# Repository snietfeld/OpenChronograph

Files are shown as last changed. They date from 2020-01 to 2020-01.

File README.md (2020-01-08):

<p align="center">
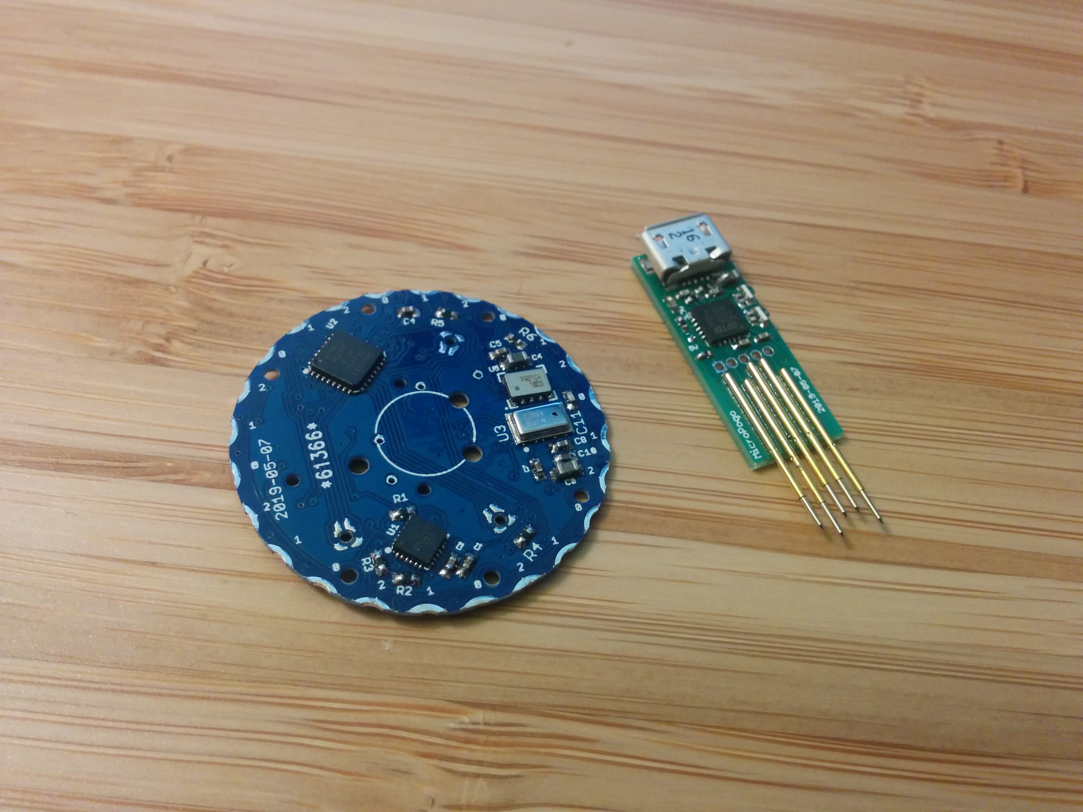
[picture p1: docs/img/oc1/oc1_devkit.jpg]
    
</p>

# What's this?
OpenChronograph is an a Arduino-compatible hybrid smartwatch platform built around Soprod micromotors. The majority of hybrid smartwatches available today (Skagen, Fossil) use these micromotors, and many are based on the same Soprod reference design. The OpenChronograph mainboards are intended to be programmable drop-in replacements for a large number of commercial hybrid smartwatches, with a suite of handy sensors. You can also create custom dials using a process described [here](https://github.com/snietfeld/OpenChronograph/tree/master/Dials).

<p align="center">
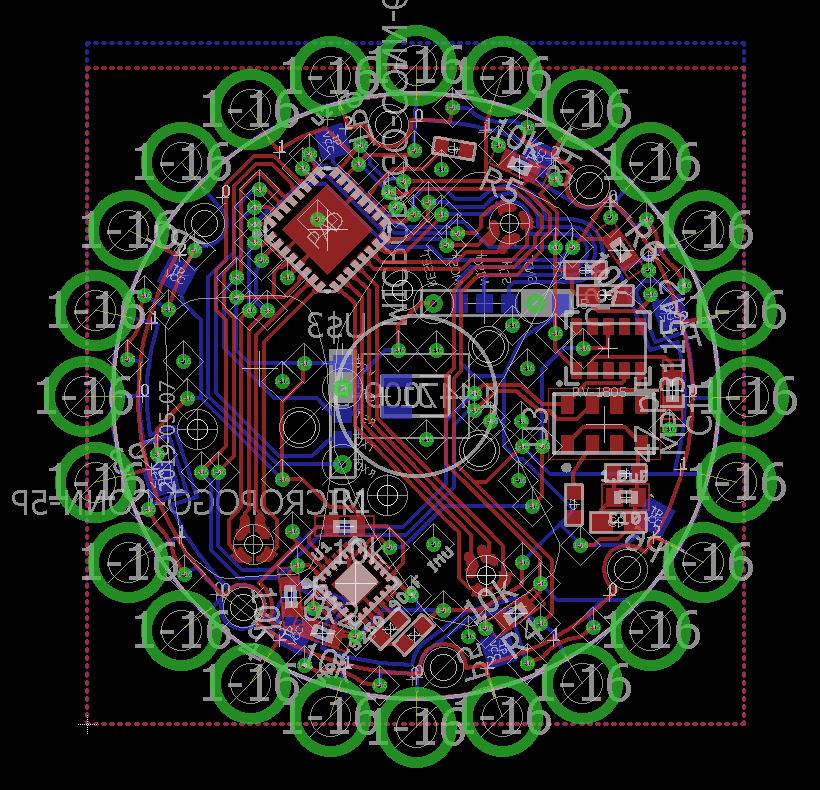
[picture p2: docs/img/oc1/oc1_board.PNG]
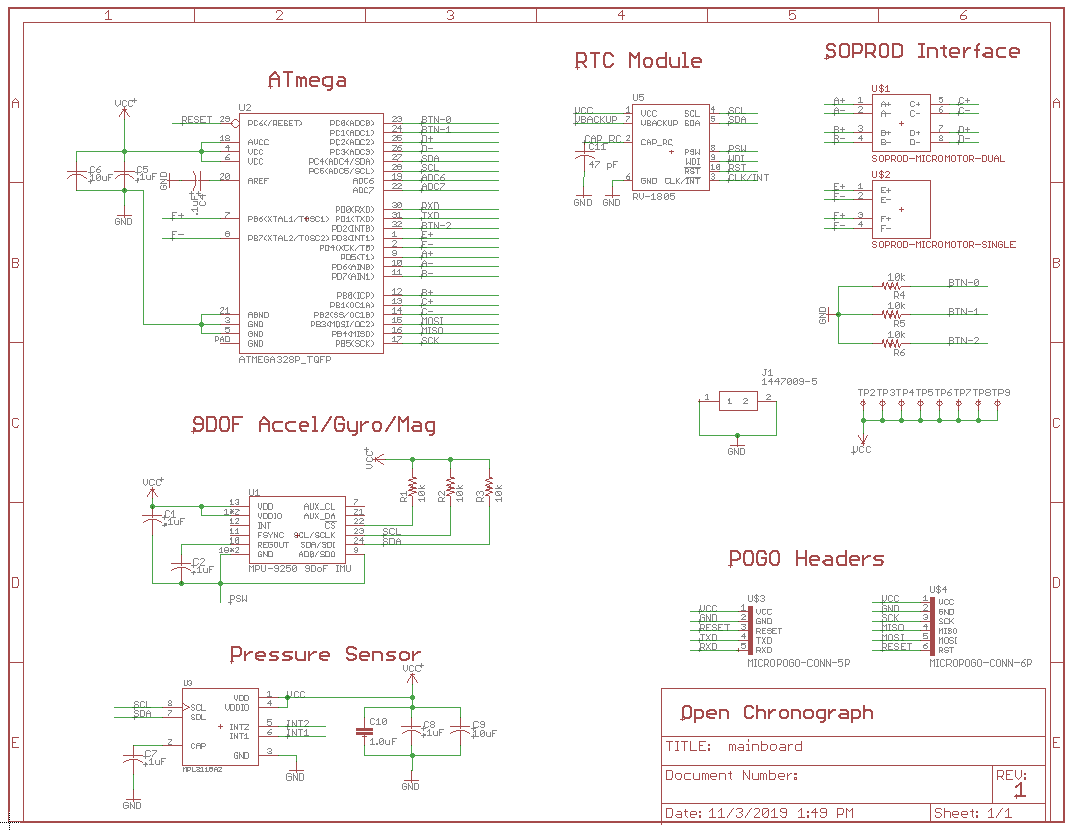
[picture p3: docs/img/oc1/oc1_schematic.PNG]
       
</p>

Platform Features:
 - Arduino-compatible Atmega328p microcontroller
 - Ultra-low-power RV-1805-C3 real-time clock
 - Precision MPU-9250 6DOF IMU + 3-axis magnetometer
 - High-precision MPL3115A2 pressure/altitude/temperature sensor
 - Support for both dual- and single-rotor micromoters (for a total of three hands)
 - Forward and retrograde hand motion
 - Custom reduced-footprint pogo-pin programmer
 
Confirmed Drop-in Compatible Watches:
 - Skagen Connected
 - Skagen Hagen
 - Fossil Q Activist
 - Fossil Q Men's Machine

# Yes, but why?
Hybrid smartwatches are neat, and they can offer fantastic battery life compared to modern smartwatches. Unfortunately, experimenting with them is difficult due to the closed nature of available designs. This project is intended to open up hybrid smartwatch design to the maker community.

# Getting started.
## What you’ll need
 - A Torx T2 driver
 - A small flathead driver
 - Watch hand pullers
 - Tweezers 
 
## Watch disassembly and board swap
(https://youtu.be/Nqi1F6wrvCc) 

## Arduino IDE Set Up
Download the Arduino IDE (tested with 1.8.9)

Clone or download this repository.

### Add the board profile
From the downloaded repository, copy the \OpenChronograph\MainBoards\oc_1\hw\Arduino_OpenChronograph_OC1 folder to your Arduino hardware folder, e.g., "C:\Program Files (x86)\Arduino\hardware\"

You should now see "OpenChronograph OC-1 (8MHz internal clock)" available in your Tools-->Board list in the Arduino IDE.

WARNING: If you skip this step, you can brick your microcontroller.

## Programming
Open the \OpenChronograph\MainBoards\oc_1\fw\oc_1_default\oc-1-default.ino project file

Select Tools --> Board --> OpenChronograph OC-1 (8MHz internal clock)

Select Tools --> Programmer --> USBtinyISP

Compile & upload using the MicroPogo programmer
<p align="center">
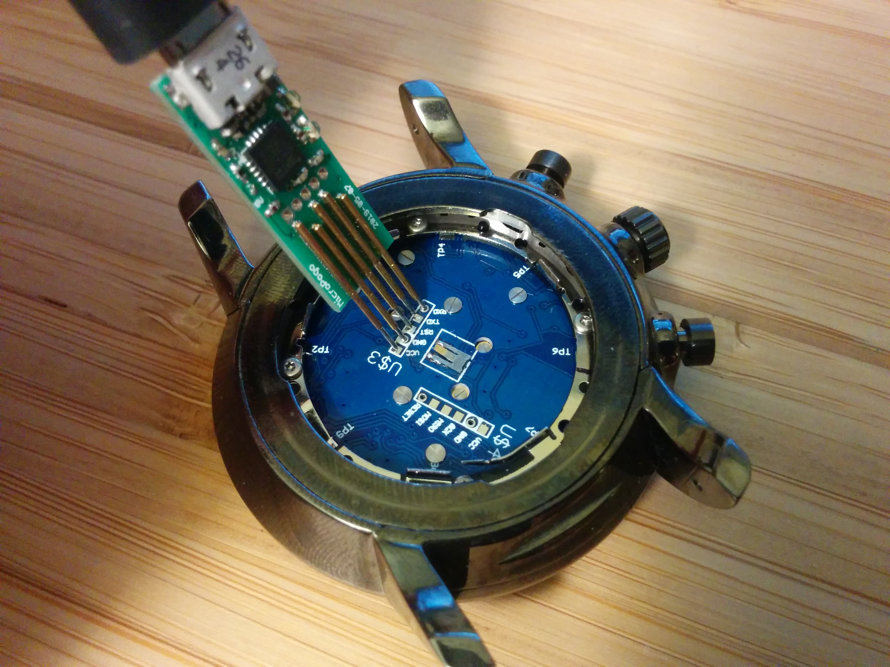
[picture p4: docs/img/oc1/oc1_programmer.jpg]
    
</p>
 
 ## MicroPogo Programmer
 The MicroPogo programmer is a small-footprint Arduino serial programmer. The footprint is derived from the Protofusion [ProtoProg Programmer](http://protofusion.org/wordpress/2013/05/open-hardware-pogo-pin-programmer/), and the board is derived from TinyCircuit's [TinyLilly Mini USB Adadpter](https://tinycircuits.com/products/tinylily-mini-usb-adapter).

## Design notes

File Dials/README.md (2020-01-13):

# Creating Custom Watch Dials With Python and PCBs
<p align="center">
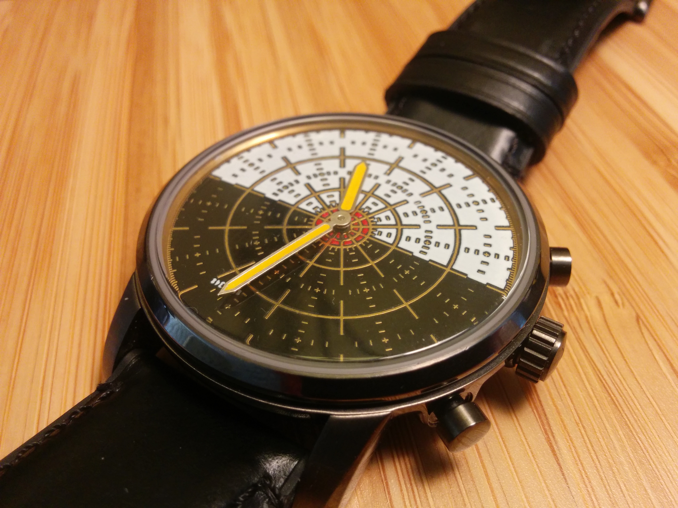
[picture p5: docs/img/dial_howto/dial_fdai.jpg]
    
</p>

## Why use PCBs?
The PCB manufacturing process is great for watch dials for a few reasons:

**Resolution**
It's common even for cheaper board houses to offer 6mil/0.15mm traces, and some fabs do 3mil/0.075mm. On paper these feature sizes correspond roughly to 170 and 340 DPI, which on its face isn't particularly impressive; however, in practice the PCB process offers very sharp, clean edges with tolerances well below these numbers. 

**Materials**
The PCB process offers a surprising variety of options here. Typically board houses offer PCBs with a fiberglass substrate, and this can be easily drilled, sanded, and glued. A wide range of thickness options are also available, and boards as thin as 0.6mm can be ordered at no extra cost. Other substrate options such as aluminum and flexible Kapton are also available, though those are more expensive.

In terms of metallic surfaces, exposed copper can be electroplated in either nickel or gold as part of the standard PCB fab process, and at very little additional cost. It's also not uncommon for an additional electropolishing step to be offered. 

**Cost**
For small, two-layer boards, custom PCBs are very cheap. A dozen custom dials can be had for less than $40. 

### Why not Printing?
While there are a number of photo printing shops that offer 300 DPI prints in various gloss finishes, these tend to look a bit fuzzy and flat: 

<p align="center">
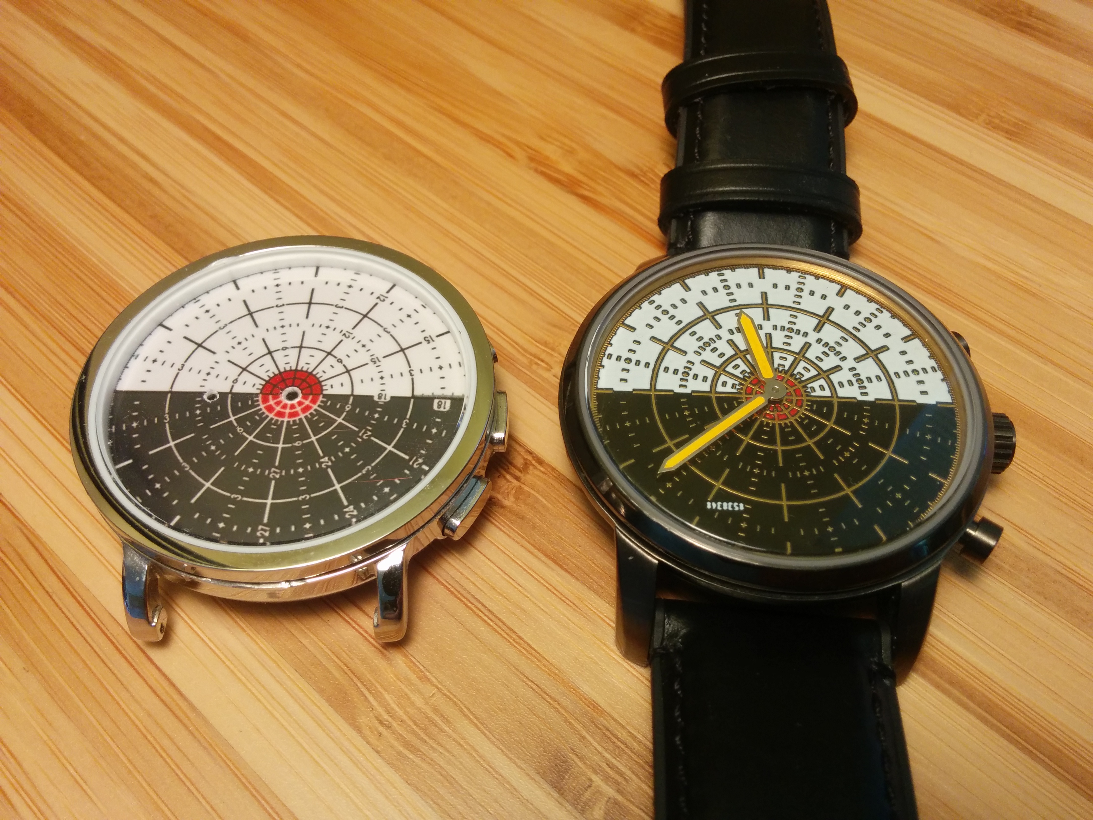
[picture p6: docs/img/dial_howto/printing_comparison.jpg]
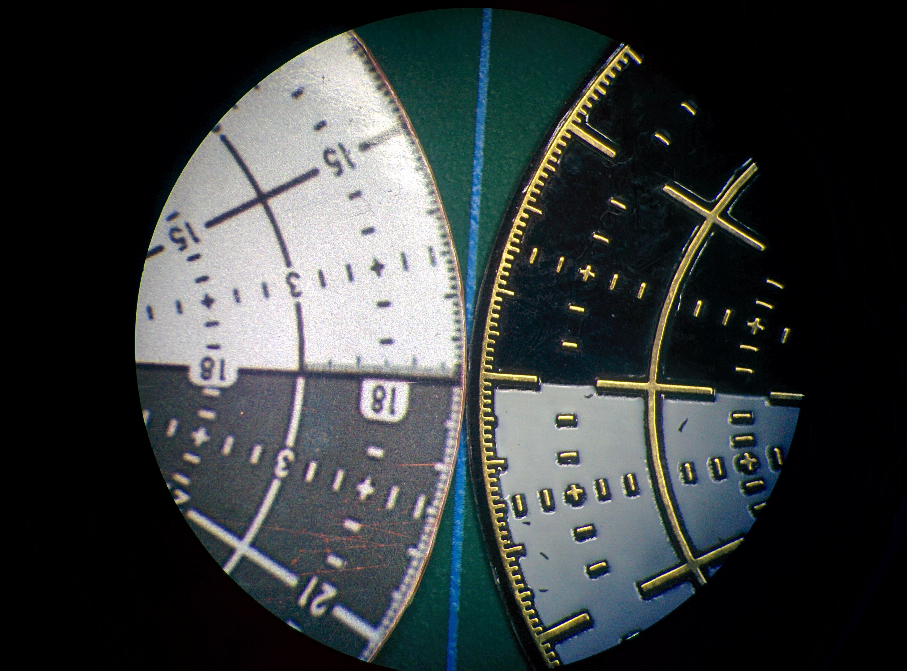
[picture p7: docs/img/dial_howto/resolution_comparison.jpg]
       
</p>

The printed paper must also be drilled to allow hand posts to pass through, which can result in fraying of the paper and wrinkling of the gloss. The outer edge must similarly be trimmed, and then the whole thing must be adhered to something such as a steel backing plate. There may be a printing workflow that produces good results, but the path is less clear compared to the PCB process.

### Disadvantages
**Color Choice** The biggest technical disadvantage is that board fabs provide limited choice in colors for soldermask and silkscreen. For one-offs this can be partly overcome by hand-painting additional colors onto the boards using common hobby enamel paints. 

**Lack of Direct PCB Art Tools** Another more practical disadvantage is that PCB layout tools such as KiCad and Eagle are designed to lay out functional electronics--not PCB art. Most likely you will draw the dial in one format and need to convert it to a different format these programs understand. Luckily, there are already well-established processes doing this.

- - -

## Step 1: Generate SVGs with Python and svgwrite
For our example I'll be using the 38mm FDAI dial. The first step was obtaining vector art of the FDAI design. Unfortunately, I was unable to find this anywhere online. Instead, I was able to generate this surprisingly easily with Python and the [svgwrite](https://pypi.org/project/svgwrite/). The full script can be found [here](https://github.com/snietfeld/OpenChronograph/blob/master/Dials/fdai_38mm/draw_fdai_dial.py). This script produces two SVG images:

<p align="center">
    
</p>

The left image will be our copper layer, and will eventually be plated in gold. The right image is our soldermask, which prevents our copper from being covered by the soldermask. We will also use the soldermask image to produce a third image for the white silkscreen.

## Step 2: Prepare Layer Bitmaps
Once our source SVGs are generated, we need to process and re-export them as high-dpi bitmaps. 

1. Open the copper SVG in GIMP
<p align="center">
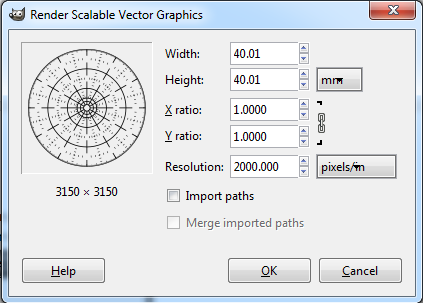
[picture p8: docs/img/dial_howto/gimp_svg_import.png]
    
</p>

2. Import the silkscreen svg as a new layer.

3. Add a new layer with a solid white color and put it at the bottom of the layer stack--this will be our white background for the copper and soldermask layers.

4. Create new layer from visible, delete and fill everything but bottom white negative space (this will be for silkscreen:
<p align="center">
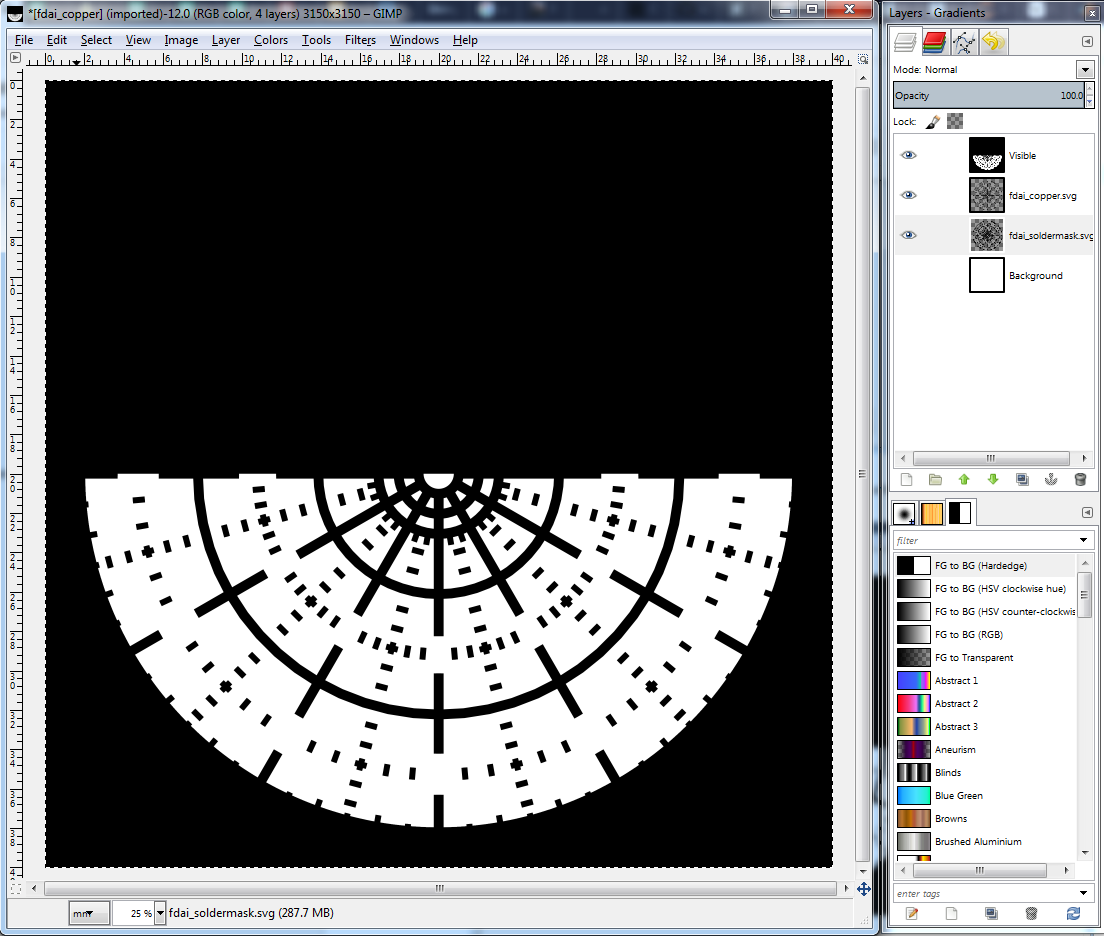
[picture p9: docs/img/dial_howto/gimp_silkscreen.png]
    
</p>

5. Set color mode to 256 colors by going to IMAGE-->MODE-->Indexed…
Set to 256 and hit CONVERT
<p align="center">
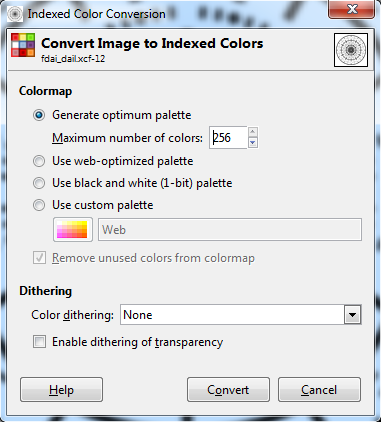
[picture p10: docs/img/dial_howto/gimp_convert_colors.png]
    
</p>

6. Export different layers to copper, soldermask, and silkscreen BMP images. You should end up with three BMP files corresponding to the copper, soldermask, and silkscreen layers:
<p align="center">
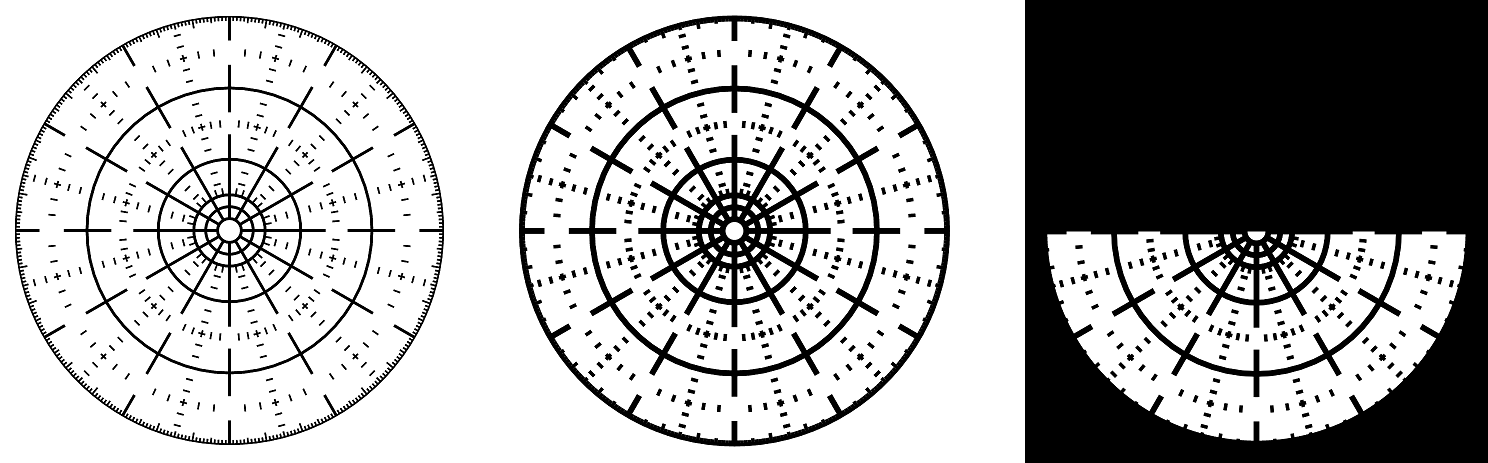
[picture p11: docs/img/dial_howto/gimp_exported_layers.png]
    
</p>

## Step 3: Import into EagleCAD
1. Go to File-->Import..-->BMP…

2. Eagle needs to know which pixel color to use for the layer being imported. Click “Scan Colors”, then select black for the copper and soldermask images, and white for the silkscreen image.

3. Set format to DPI, units to inches, and be sure to set the value for DPI to correspond to the DPI setting used when importing the SVG into GIMP (in this case, 2000). Then set the layer ID number to import to (1 - top copper, 21 - top silkscreen, 29 - top soldermask): 
<p align="center">
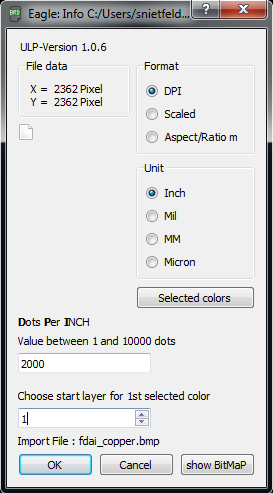
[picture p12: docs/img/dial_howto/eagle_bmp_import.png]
    
</p>

Useful layer numbers

Layer ID | Description | Final Color
--- | --- | ---
1 | Top Copper | Gold
21 | Tplace (silkscreen) | White 
29 | Tstop (soldermask) | Black

There’s some discretization that occurs due to the way the BMPs are rasterized, but I’ve set the DPI to 2000 here--much higher level of detail than the fab lab can print.

<p align="center">
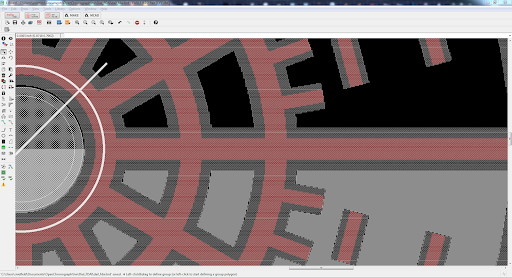
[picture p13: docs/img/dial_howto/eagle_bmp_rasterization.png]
    
</p>

## Step 4: Export GERBER files and send off to fab
This step will vary depending on which board fab you use. I have had great luck with DirtyPCBs, so I'll use them as an example. 

1. Save your Eagle design file
2. Click File-->CAM Processor
2. In the new window, click File-->Open-->Job
<p align="center">
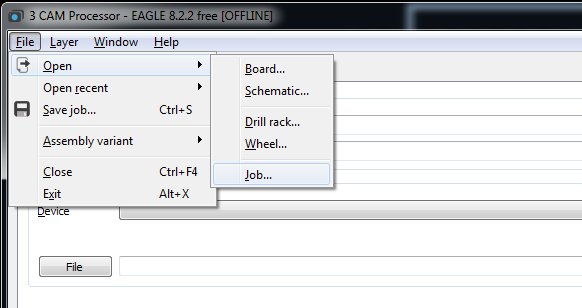
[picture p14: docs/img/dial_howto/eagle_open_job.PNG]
    
</p>
3. Select the DirtyPCBs cam job file:
<p align="center">
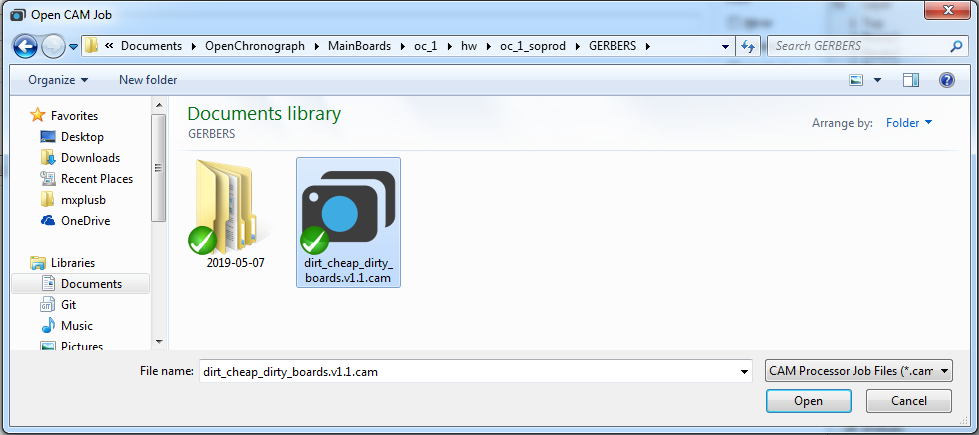
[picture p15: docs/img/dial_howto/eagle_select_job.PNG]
    
</p>

4. Click "Process Job"

5. Place the generated GERBER files in to a .zip, and upload using DirtyPCBs website. Be sure to select 0.6mm board thickness.
<p align="center">
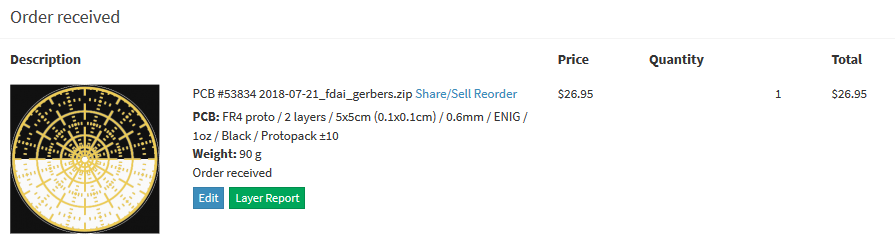
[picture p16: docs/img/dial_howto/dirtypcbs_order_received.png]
    
</p>

## Step 5: Painting
Once the dials are received, they can be sanded to thickness or diameter if needed. Any colors that weren't included in the board itself can be painted using enamel modeling paints and miniature brushes. A binocular microscope really helps here, and islands of soldermask or silkscreen can be used to constrain paint edges through surface tension. Small mistakes can usually be scraped off after drying with a pick. 

<p align="center">
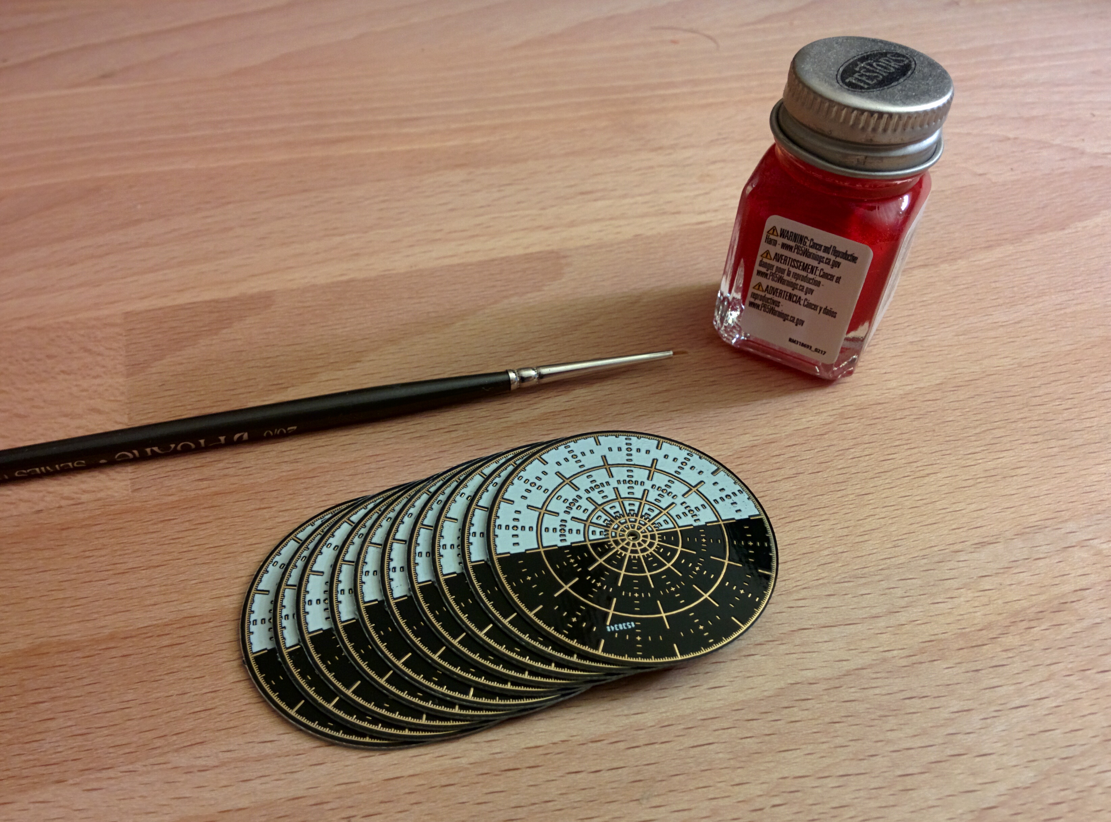
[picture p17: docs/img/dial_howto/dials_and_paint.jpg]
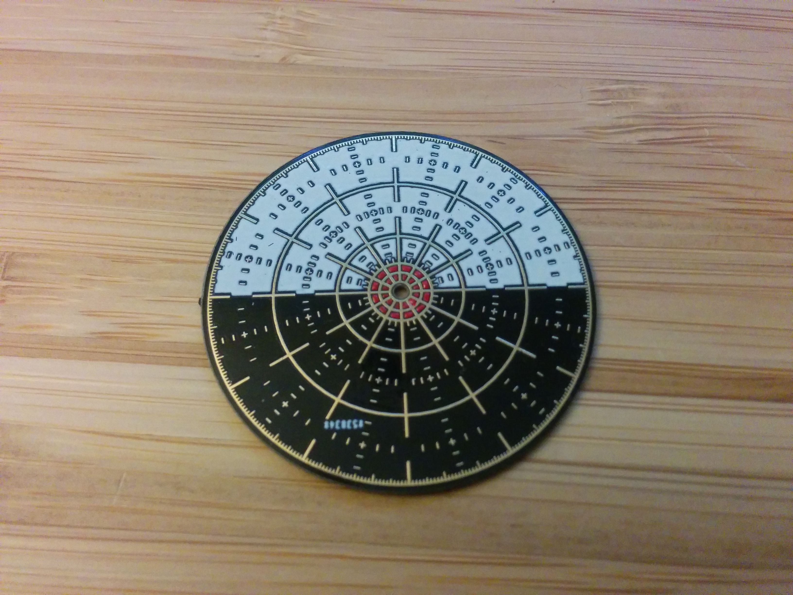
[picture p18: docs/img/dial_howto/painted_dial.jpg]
     
</p>

## Step 6: Mechanical Integration
In most cases, the dial being replaced is flat and close to the same 0.6mm thickness as the PCB. In these cases the dial can be substituted in directly without any additional steps. However, in this particular watch, the edge of the original dial is curved upwards, increasing its effective thickness: 

<p align="center">
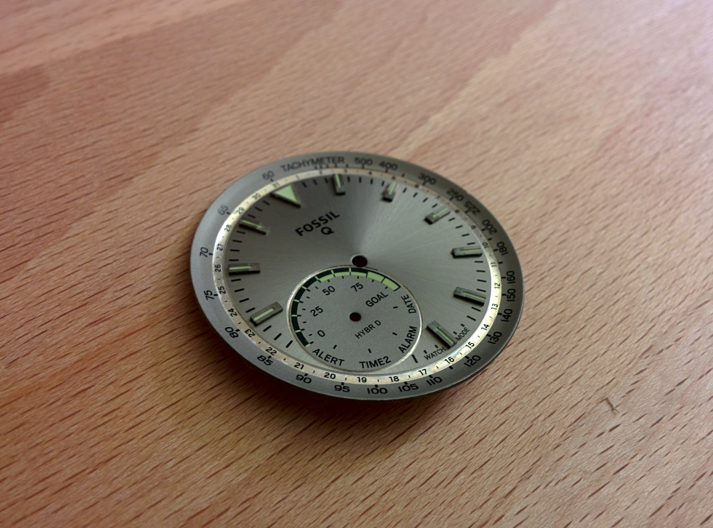
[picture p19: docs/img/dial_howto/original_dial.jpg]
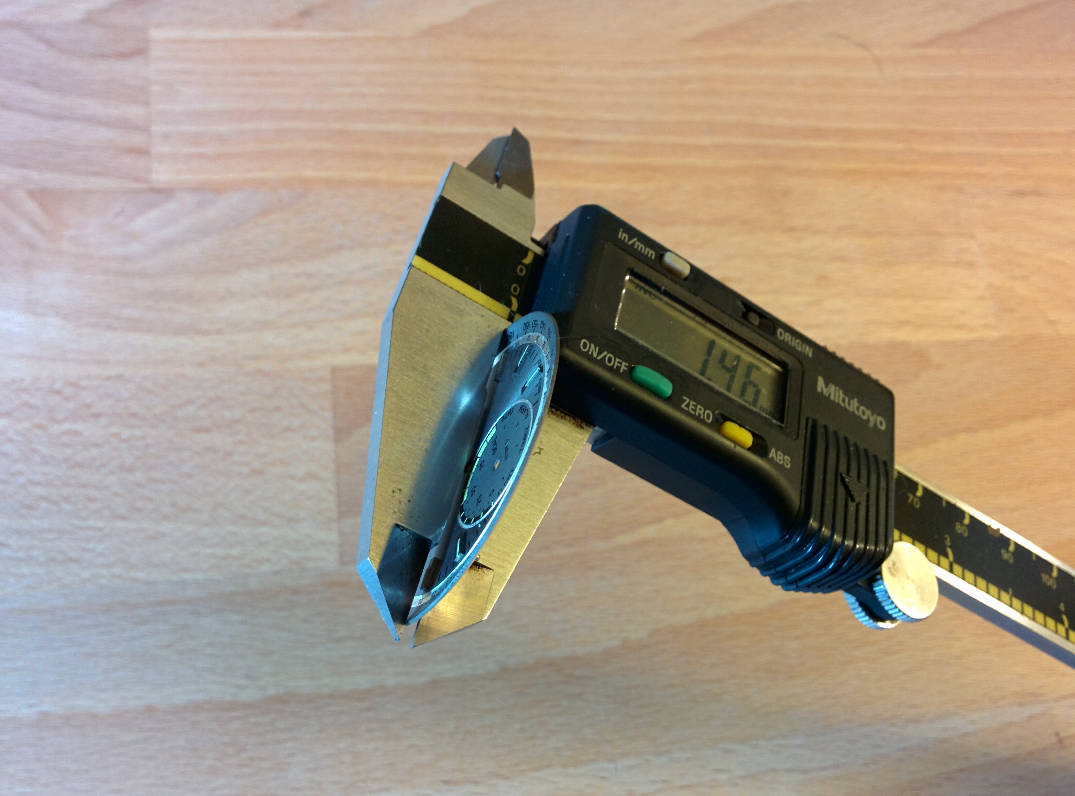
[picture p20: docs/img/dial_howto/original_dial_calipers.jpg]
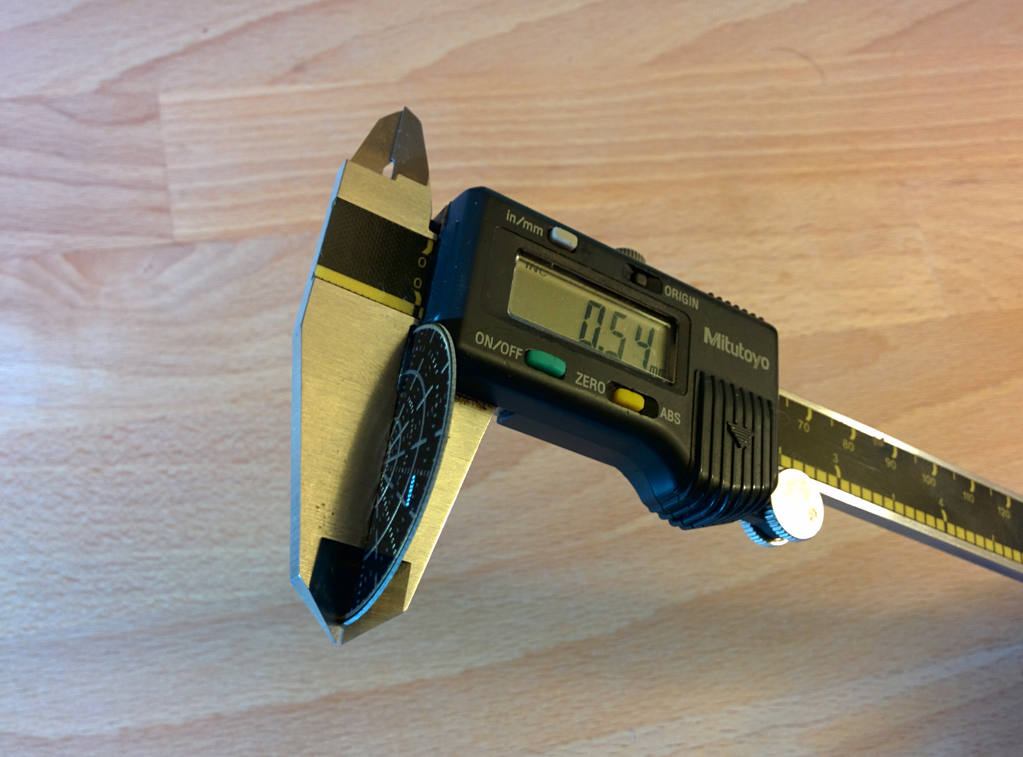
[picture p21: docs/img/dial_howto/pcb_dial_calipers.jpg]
     
</p>

If we tried to use the PBC dial directly here, there would be a gap between the dial and the glass. Since the inner assembly stack is pressed from behind by the battery case foam, this would cause the entire assembly to travel forward, pressing the minute hand motor shaft into the glass and preventing it from turning. To overcome this and maintain the correct spacing, a brass spacer ring was turned on a lathe and electroplated with gold.

<p align="center">
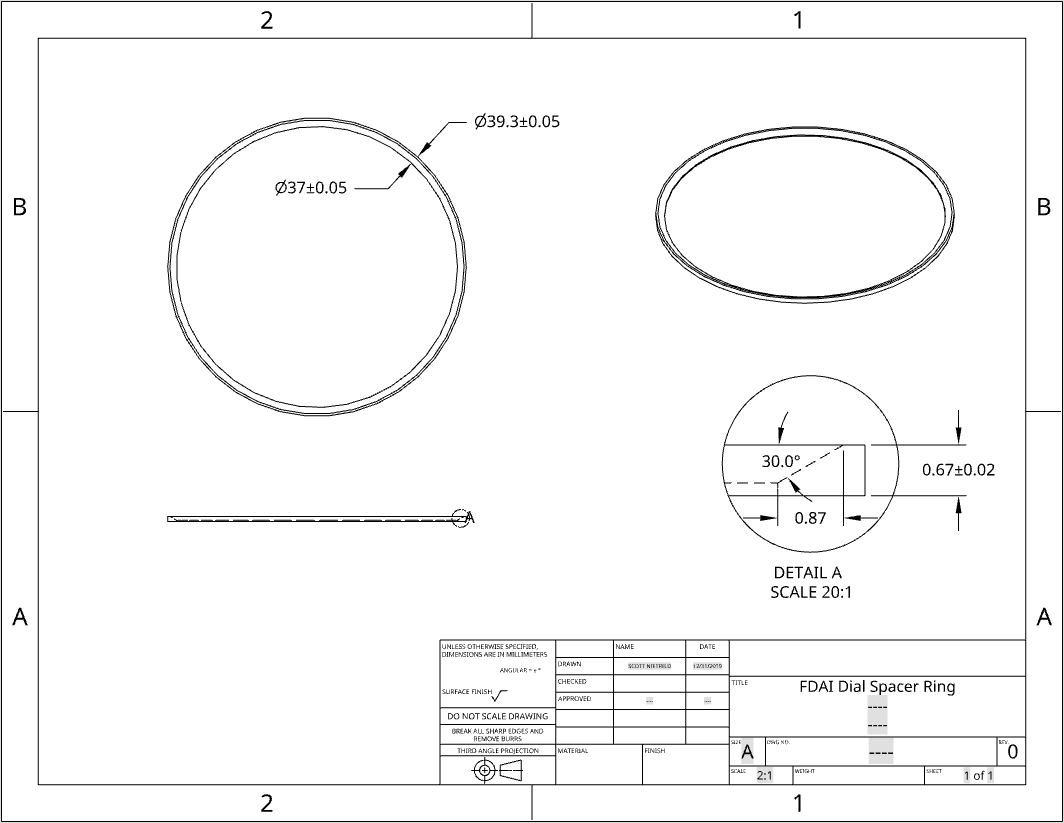
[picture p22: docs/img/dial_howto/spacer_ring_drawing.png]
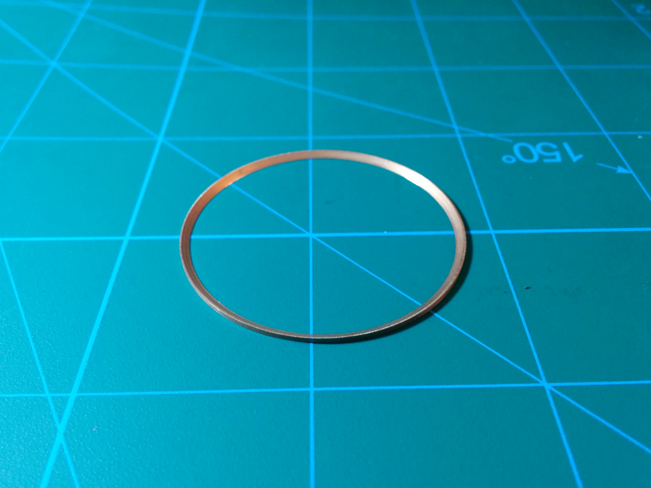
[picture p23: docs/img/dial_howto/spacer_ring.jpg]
    
</p>

# Design Tools and Workflow
The FDAI example above is a fairly specific one-off design, but I've written a small utility library, [dial_util.py](https://github.com/snietfeld/OpenChronograph/blob/master/Dials/tools/dial_util.py), for drawing simple dials and subdials. The dials below were all generated using this module, and the scripts to generate them can be found in the [OpenChronograph\Dials](https://github.com/snietfeld/OpenChronograph/tree/master/Dials) directory.

<p align="center">
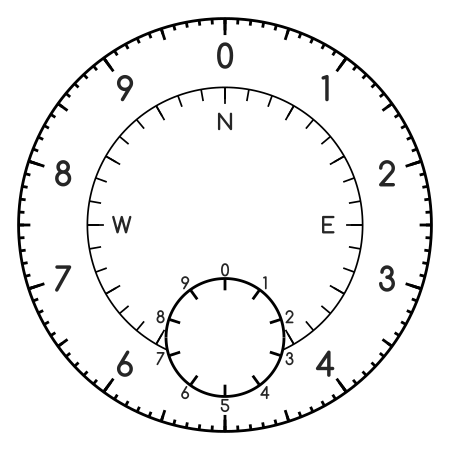
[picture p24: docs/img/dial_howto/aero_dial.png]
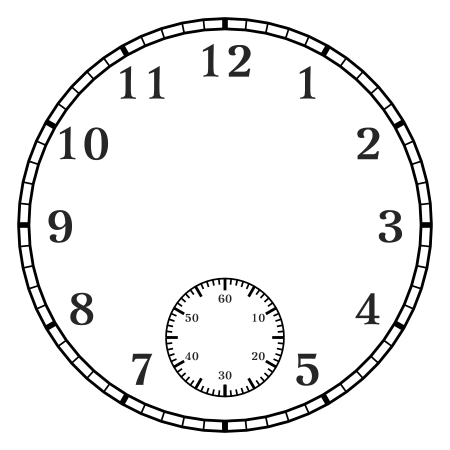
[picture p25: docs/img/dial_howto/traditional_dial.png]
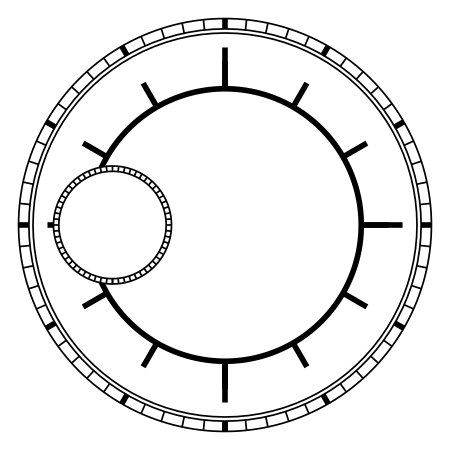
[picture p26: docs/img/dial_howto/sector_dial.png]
     
</p>

I also wrote a small Python tool, [svgviewer](https://github.com/snietfeld/OpenChronograph/blob/master/Dials/tools/svgviewer.py), that displays an updated view of the image output as a dial script is edited.

Example usage:
```
cd OpenChronograph/Dials/tools
python svgviewer.py ./../aero_38mm/gen_aero_dial.py ./../aero_38mm/aero_copper.svg --width 450 --height 450
```

The command above will cause svgviewer to rerun gen_aero_dial.py every time it is modified, then display the outputted image (aero_copper.svg).

<p align="center">
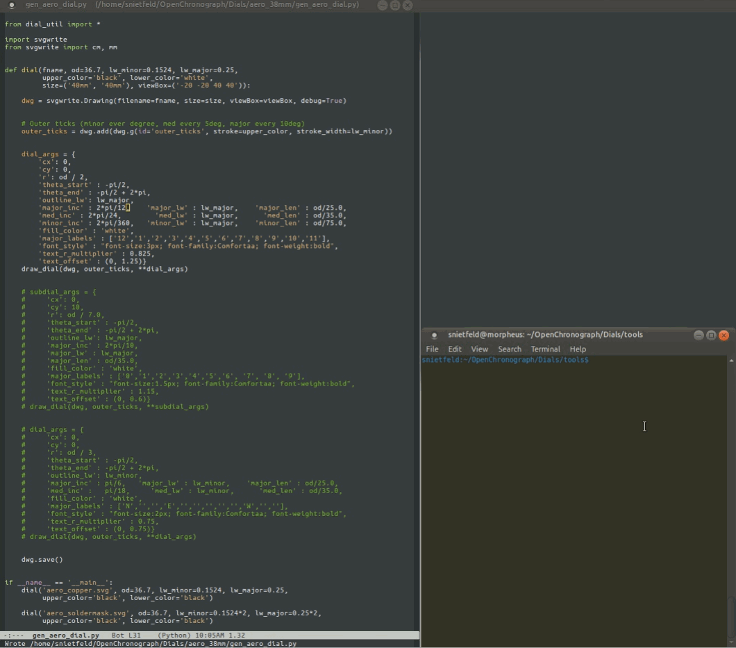
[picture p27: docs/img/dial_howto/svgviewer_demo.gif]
    
</p>

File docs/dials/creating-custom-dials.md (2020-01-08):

=== Creating Custom Watch Dials With Python and PCBs ===

== Why use PCBs? ==
The PCB manufacturing process is great for watch dials for a few reasons:

*Resolution*
It's common even for cheaper board houses to offer 6mil/0.15mm traces, and some fabs do 3mil/0.075mm. On paper these feature sizes correspond roughly to 170 and 340 DPI, which isn't on its face particularly impressive; however, in practice the PCB process offers very sharp, clean edges with tolerances well below these numbers. 

*Materials*
The PCB process offers a surprising variety of options here. Typically board houses offer PCBS with a fiberglass substrate, and this can be easily drilled, sanded, and glued. A wide range of thickness options are also available, and boards as thin as 0.6mm can be ordered at no extra cost. Other substrate options such as aluminum and flexible Kapton are also available, though those are more expensive.

In terms of metallic surfaces, exposed copper can be electroplated in either nickel or gold as part of the standard PCB fab process, and at very little additional cost. It's also not uncommon for a additional electropolishing step to be offered. 

*Cost*
For small, two-layer boards, custom PCBs are very cheap. A dozen custom dials can be had for less than $40. 

== Why not Printing? ==
While there are a number of photo printing shops that offer high DPI prints in various gloss finishes, these tend to look fuzzy and flat. The printed paper must also be drilled to allow hand posts to pass through, which can result in fraying of the paper and wrinkling of the gloss. The outer edge must similarly be trimmed, and then the whole thing must be adhered to something such as a steel backing plate. There may be a printing workflow that produces good results, but the path is less clear compared to the PCB process.

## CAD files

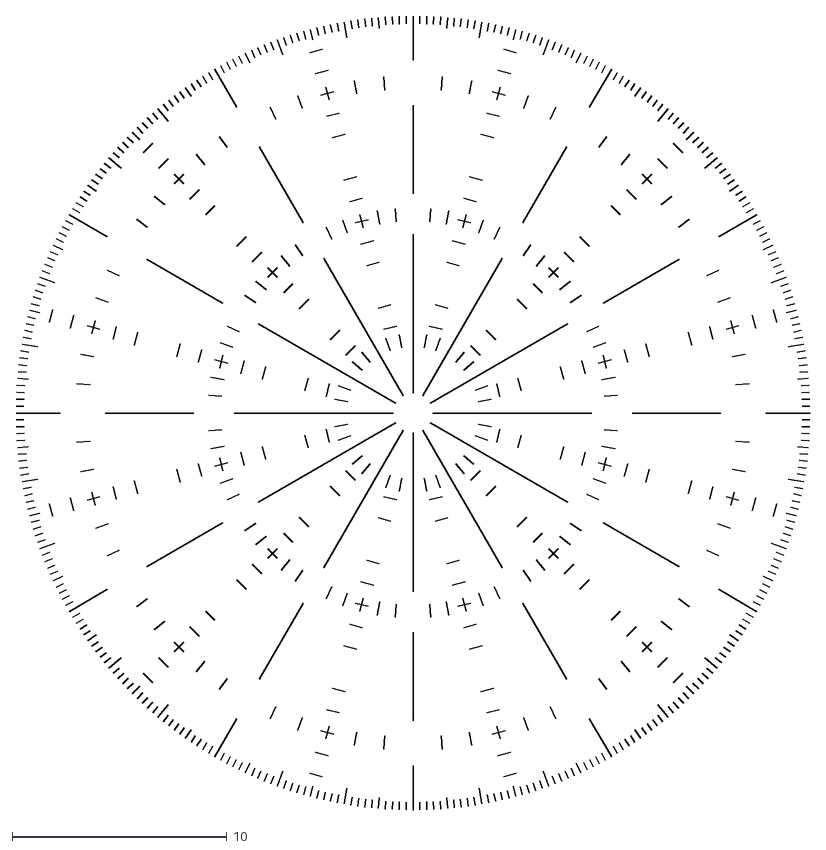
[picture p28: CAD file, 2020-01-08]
Dials/fdai_38mm/source_img/fdai.dxf
37.0 x 37.0

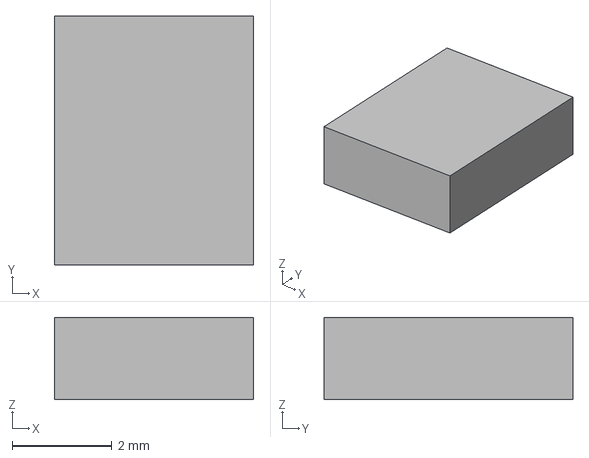
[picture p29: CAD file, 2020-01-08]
MainBoards/oc_1/hw/oc_1_soprod/Eagle_Libs/IC_Maxim_DS3231MZ+/bcd90fdfe0211a008e479c846e3d104fc3feab37.step
4.00 x 5.00 x 1.65 mm

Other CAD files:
MainBoards/oc_1/hw/oc_1_soprod/Eagle_Libs/IC_Maxim_DS3231MZ+/b415eedf545dbc7bcc4de6bb77471575da4e3105.step
MainBoards/oc_1/hw/oc_1_soprod/Eagle_Libs/IC_Maxim_DS3231MZ+/45010c6b30a930e722395be228df71050403c276.step

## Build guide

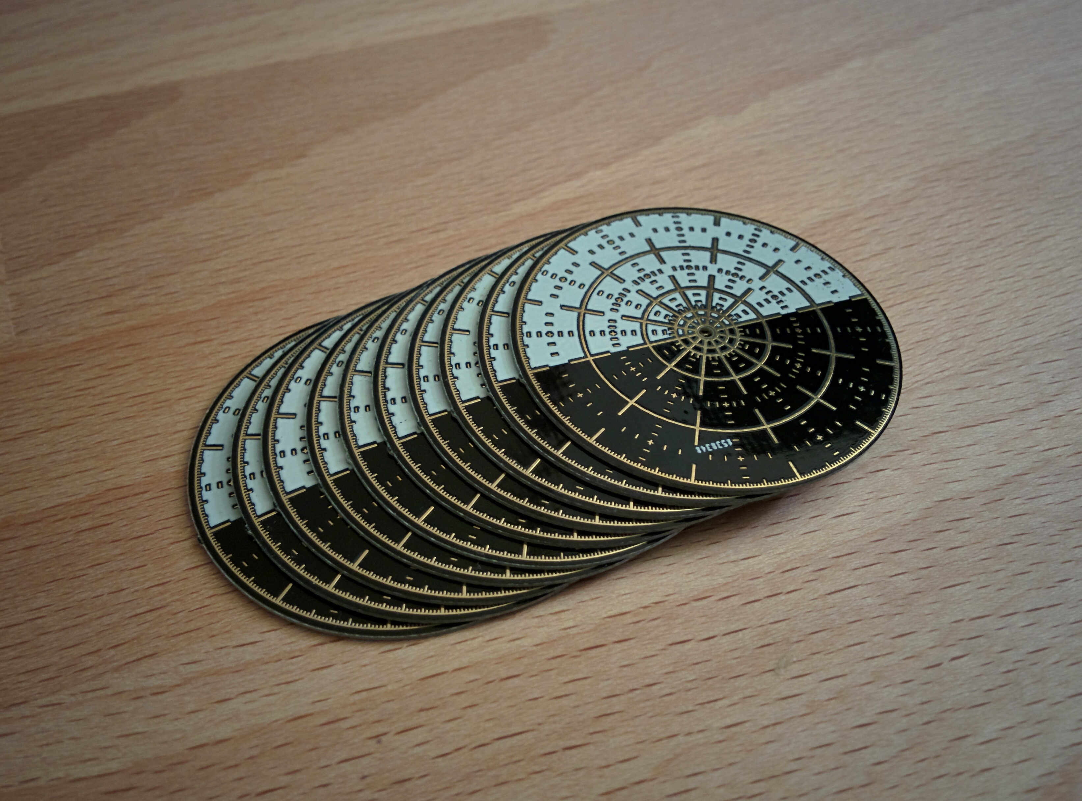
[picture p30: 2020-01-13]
docs/img/dial_howto/bare_dial_pcbs.jpg

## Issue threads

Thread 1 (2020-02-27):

Boards availability.

dwhacks, 2020-02-27:
Are you planning on making boards available for purchase? I’d love to tackle this project but don’t really want to order 5x each board and parts to build only one watch.

Any plans for even a kit or assembled boards or am I on my own.

Also, the disassembly video, what watch is that? I couldn’t figure it out from the list of “drop in watches”.

snietfeld, 2020-02-27:
The original watch in the video is a Goodwin hybrid model [FTW1171](https://www.fossil.com/en-us/products/hybrid-smartwatch-goodwin-black-leather/FTW1171.html). That specific model isn't being sold anymore as far as I can tell, but you can still find them on ebay occasionally. If you can't find that, then it looks like the Fossil Neutra line uses the same case design, with the [Neutra Amber](https://www.fossil.com/en-us/products/hybrid-smartwatch-neutra-amber-leather/FTW1194.html) being the closest fit.

I have a small number of kits built up, including mainboard and programmer (but not the watch) available here: https://www.tindie.com/products/oclabs/openchronograph-oc-1-devkit/

dwhacks, 2020-02-27:
Perfect! I am in Canada so tindie wouldn’t let me purchase and said they have sent you a message about shipping to Canada. Please let me know if that’s possible. Really like this project.

snietfeld, 2020-02-28:
Ah okay, I just added a flat rate shipping option for Canada--let me know if you have any issues.

dwhacks, 2020-02-28:
Thanks. Shipping to Canada is more then I would hope so I will have to find another way. I lve close to the US border so I may be able to ship it there and drive across to pick it up. Thanks for the great project.

snietfeld, 2020-02-28:
Yeah it seemed high to me too, but I'm not super familiar with international shipping. Is there a cheaper carrier or shipping method you'd recommend?

dwhacks, 2020-02-28:
USPS is definitely the cheapest, and most reliable. I think the problem is the "flat rate international priority". Being Canadian I don't really know what the options are, but for example, I have a radio controlled airplane kit box in my hand that went from Florida to Montreal for $4.90 (printed stamp says price). The box is 3"x6"x30". Another one, $5.75 and says "USPS AIRMAIL".

MadBean pedals will send "flats" for $5 and these are usually a small bubble envelope with a piece of cardboard and the circuit board tapped to it. I have got circuit boards with DIP chips shipped that way.

According to the USPS site, "First-Class Mail International, large envelopes (flats)" is the [cheapest](https://www.usps.com/business/prices.htm), Next up is "First-class package international" starting at $12+

If you're willing to go to a post office with it packaged in a bubble envelope and get a quote I would gladly pay the shipping + packaging costs and could send you paypal directly. Maybe it's tindie that doesn't have a shipping good option?

I'm not trying to be a pain here, or undervalue your time.

e-mail me @ forsakenrider at hotmail dot com

snietfeld, 2020-02-28:
Thanks for providing the other postage prices for comparison--glad to see there are cheaper methods out there. I'm out of town this weekend, but I'll make a run to the post office when I get back to find out what the options are.

dwhacks, 2020-02-28:
excellent, thank you!

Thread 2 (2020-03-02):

Bluetooth roadmap?

g2010a, 2020-03-02:
Hi, it doesn't seem like the board offers Bluetooth connectivity. It's there a plan to add it later? Thanks. And awesome concept, btw.

snietfeld, 2020-03-03:
Thanks! There is indeed no connectivity in the current design, and the haptic has also been removed to make room for sensors. I will probably not pursue those features myself, but I’d be happy to support anyone who’s interested in doing so.

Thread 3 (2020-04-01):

Watch Compatibility

ABianchini, 2020-04-01:
What determines if a watch would be compatible with this board? Would this one work: [FTW1150](https://www.fossil.com/en-us/products/hybrid-smartwatch-commuter-dark-brown-leather/FTW1150.html)

snietfeld, 2020-04-02:
I'm 95% sure the watch you listed would be fine, but I haven't tested that specific model so I can't say for certain. I can say that the Fossil Q Activist and Fossil Q Men's Machine are both compatible, and this watch looks like it's from the same family. I also can't say whether this watch uses a thin battery or the higher-capacity CR2430 (highly recommend watches designed for the CR2430).

The good news is that you won't have to void the warranty to find out if it's compatible. If you open the back up and pull the battery out, you'll be able to see pretty clearly if it's using the Soprod board and motors.

You might also join our Discord channel for more discussion here: https://discord.gg/hkmDgSk

ABianchini, 2020-04-02:
Thank you very much!

Closed 2020-04-02.

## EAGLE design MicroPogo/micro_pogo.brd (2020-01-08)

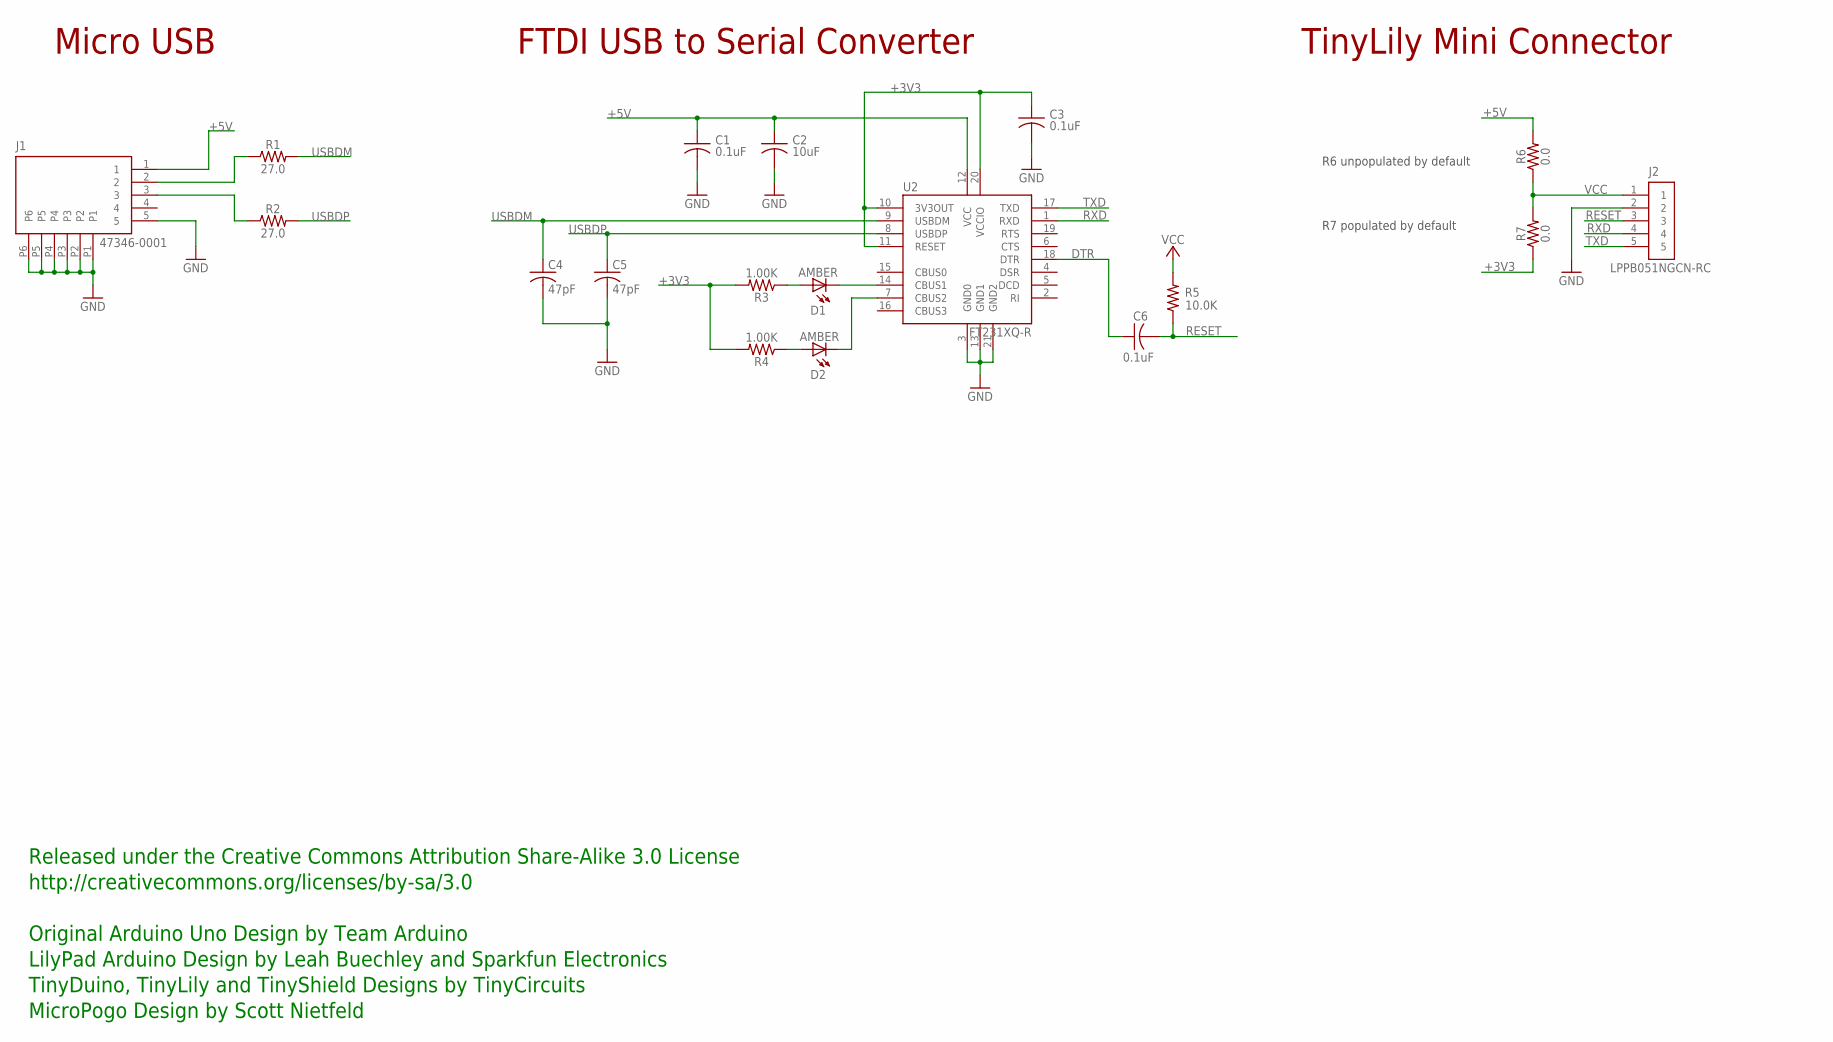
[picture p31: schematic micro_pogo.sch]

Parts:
C1: 0.1uF; C0402
C2: 10uF; C0603
C3, C6: 0.1uF; C0402; PARTNO AS-ITM-00008
C4, C5: 47pF; 0402; PARTNO AS-ITM-00241
D1, D2: AMBER; LNJ_LED
J1: 47346-0001; MICRO_USB; PARTNO AS-ITM-00021
J2: LPPB051NGCN-RC; 1X5_.05_RA_TH_RECPT
R1, R2: 27.0; 0402
R3, R4: 1.00K; 0402
R5: 10.0K; 0402
R6, R7: 0.0; 0402
U2: FT231XQ-R; QFN20

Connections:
+3V3: C3.1, R3.2, R4.2, R7.1, U2.10 (3V3OUT), U2.11 (RESET), U2.20 (VCCIO)
+5V: C1.1, C2.1, J1.1, R6.2, U2.12 (VCC)
DTR: C6.1, U2.18 (DTR)
GND: C1.2, C2.2, C3.2, C4.2, C5.2, J1.5, J1.P1, J1.P2, J1.P3, J1.P4, J1.P5, J1.P6, J2.2, U2.3 (GND0), U2.13 (GND1), U2.21 (GND2)
unnamed: D2.C, U2.7 (CBUS2)
unnamed: D1.A, R3.1
unnamed: D2.A, R4.1
unnamed: J1.2, R1.1
unnamed: J1.3, R2.1
unnamed: D1.C, U2.14 (CBUS1)
RESET: C6.2, J2.3, R5.1
RXD: J2.4, U2.1 (RXD)
TXD: J2.5, U2.17 (TXD)
USBDM: C4.1, R1.2, U2.9 (USBDM)
USBDP: C5.1, R2.2, U2.8 (USBDP)
VCC: J2.1, R5.2, R6.1, R7.2

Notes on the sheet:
R7 populated by default
Micro USB
FTDI USB to Serial Converter
TinyLily Mini Connector
Released under the Creative Commons Attribution Share-Alike 3.0 License
http://creativecommons.org/licenses/by-sa/3.0
Original Arduino Uno Design by Team Arduino
TinyDuino, TinyLily and TinyShield Designs by TinyCircuits
LilyPad Arduino Design by Leah Buechley and Sparkfun Electronics
R6 unpopulated by default
MicroPogo Design by Scott Nietfeld

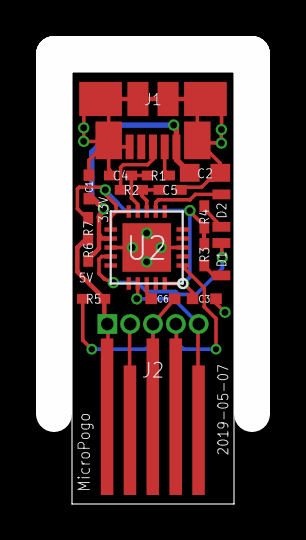
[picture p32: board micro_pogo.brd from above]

Board: 2 copper layers, 11.0 x 25.0 mm, 18 parts (0 on the bottom side), 16 nets.

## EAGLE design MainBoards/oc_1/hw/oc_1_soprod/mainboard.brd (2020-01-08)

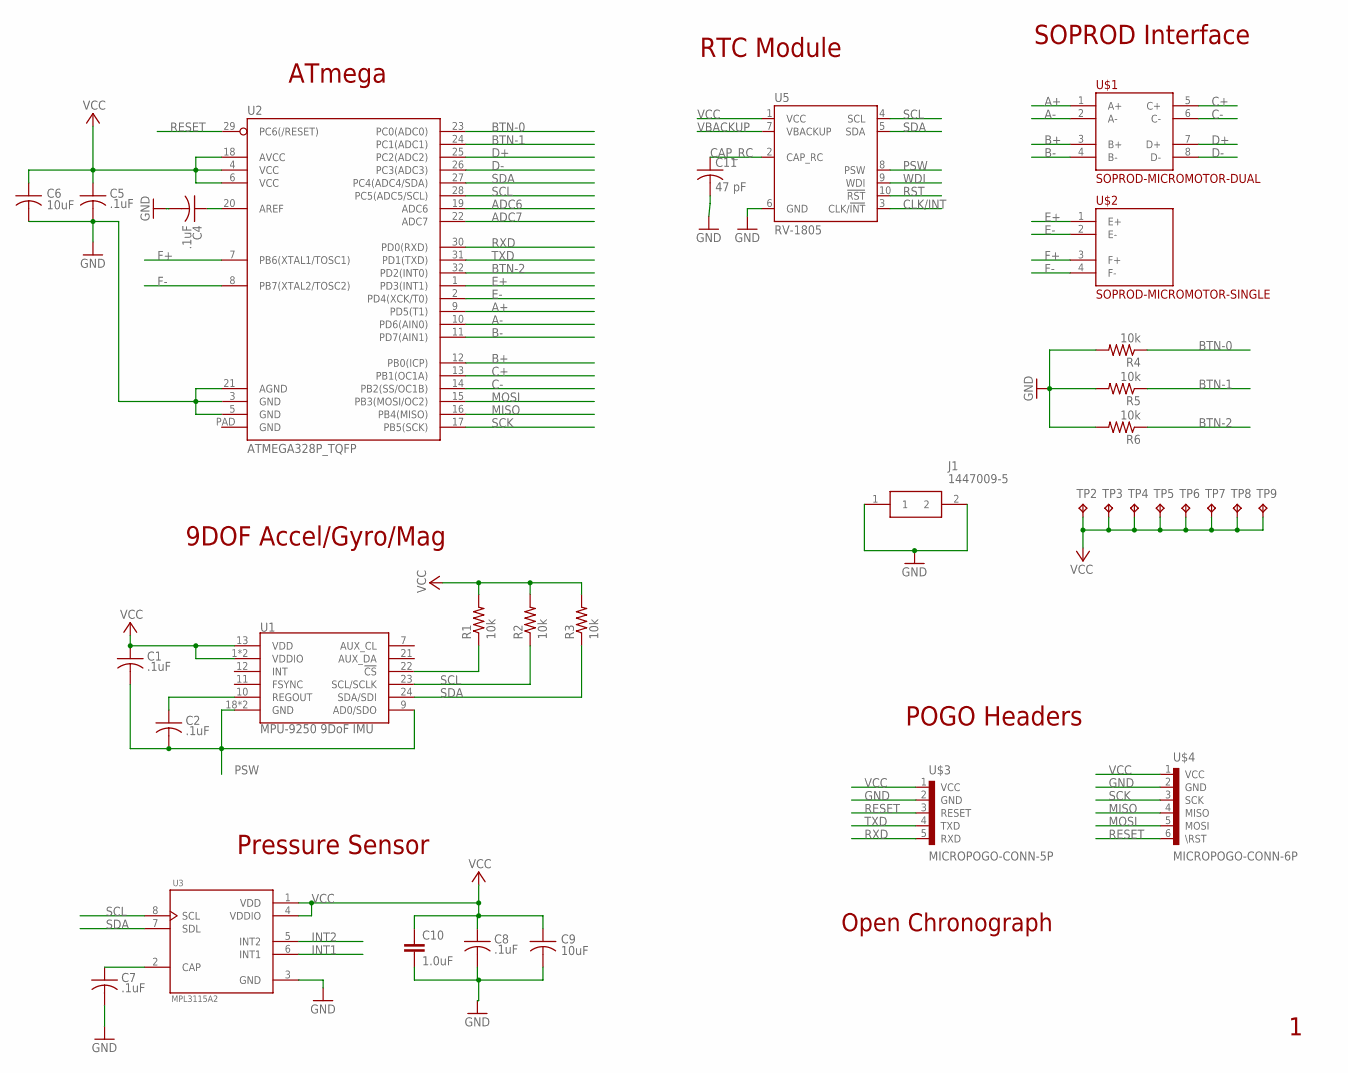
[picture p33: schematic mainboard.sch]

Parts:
C1, C2, C4, C5, C7, C8: .1uF; C0402
C6, C9: 10uF; C0603
C10: 1.0uF; 0402
C11: 47 pF; C0402
J1: 1447009-5; 14470095
R1, R2, R3, R4, R5, R6: 10k; R0402
TP2, TP3, TP4, TP5, TP6, TP7, TP8, TP9: TPTP15SQ; TP15SQ
U1: MPU-9250 9DoF IMU; QFN24-3X3
U2: ATMEGA328P_TQFP; MLF32-PAD
U3: MPL3115A2; PSON125P300X500X120-8N
U5: RV-1805
U$1: SOPROD-MICROMOTOR-DUAL; SOPROD-DUAL
U$2: SOPROD-MICROMOTOR-SINGLE; SOPROD-SINGLE
U$3: MICROPOGO-CONN-5P; MICROPOGO-CONN-5P-ASYM
U$4: MICROPOGO-CONN-6P; MICROPOGO-CONN-6P-ASYM

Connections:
A+: U2.9 (PD5(T1)), U$1.1 (A+)
A-: U2.10 (PD6(AIN0)), U$1.2 (A-)
ADC6: U2.19 (ADC6)
ADC7: U2.22 (ADC7)
AREF: C4.1, U2.20 (AREF)
B+: U2.12 (PB0(ICP)), U$1.3 (B+)
B-: U2.11 (PD7(AIN1)), U$1.4 (B-)
BTN-0: R4.1, U2.23 (PC0(ADC0))
BTN-1: R5.1, U2.24 (PC1(ADC1))
BTN-2: R6.1, U2.32 (PD2(INT0))
C+: U2.13 (PB1(OC1A)), U$1.5 (C+)
C-: U2.14 (PB2(SS/OC1B)), U$1.6 (C-)
CAP: C7.1, U3.2 (CAP)
CAP_RC: C11.1, U5.2 (CAP_RC)
CLK/INT: U5.3 (CLK/!INT)
D+: U2.25 (PC2(ADC2)), U$1.7 (D+)
D-: U2.26 (PC3(ADC3)), U$1.8 (D-)
E+: U2.1 (PD3(INT1)), U$2.1 (E+)
E-: U2.2 (PD4(XCK/T0)), U$2.2 (E-)
F+: U2.7 (PB6(XTAL1/TOSC1)), U$2.3 (F+)
F-: U2.8 (PB7(XTAL2/TOSC2)), U$2.4 (F-)
GND: C4.2, C5.2, C6.2, C7.2, C8.2, C9.2, C10.2, C11.2, J1.1, J1.2, R4.2, R5.2, R6.2, U2.3 (GND), U2.5 (GND), U2.21 (AGND), U3.3 (GND), U5.6 (GND), U$3.2 (GND), U$4.2 (GND)
INT1: U3.6 (INT1)
INT2: U3.5 (INT2)
MISO: U2.16 (PB4(MISO)), U$4.4 (MISO)
MOSI: U2.15 (PB3(MOSI/OC2)), U$4.5 (MOSI)
unnamed: C2.1, U1.10 (REGOUT)
unnamed: R1.1, U1.22 (!CS)
PSW: C1.2, C2.2, U1.9 (AD0/SDO), U1.18 (GND), U1.20 (GND), U5.8 (PSW)
RESET: U2.29 (PC6(/RESET)), U$3.3 (RESET), U$4.6 (\RST)
RST: U5.10 (!RST)
RXD: U2.30 (PD0(RXD)), U$3.5 (RXD)
SCK: U2.17 (PB5(SCK)), U$4.3 (SCK)
SCL: R2.1, U1.23 (SCL/SCLK), U2.28 (PC5(ADC5/SCL)), U3.8 (SCL), U5.4 (SCL)
SDA: R3.1, U1.24 (SDA/SDI), U2.27 (PC4(ADC4/SDA)), U3.7 (SDL), U5.5 (SDA)
TXD: U2.31 (PD1(TXD)), U$3.4 (TXD)
VBACKUP: U5.7 (VBACKUP)
VCC: C1.1, C5.1, C6.1, C8.1, C9.1, C10.1, R1.2, R2.2, R3.2, TP2.TP, TP3.TP, TP4.TP, TP5.TP, TP6.TP, TP7.TP, TP8.TP, TP9.TP, U1.1 (VDDIO), U1.8 (VDDIO), U1.13 (VDD), U2.4 (VCC), U2.6 (VCC), U2.18 (AVCC), U3.1 (VDD), U3.4 (VDDIO), U5.1 (VCC), U$3.1 (VCC), U$4.1 (VCC)
WDI: U5.9 (WDI)

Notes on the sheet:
ATmega
Open Chronograph
SOPROD Interface
9DOF Accel/Gyro/Mag
Pressure Sensor
RTC Module
POGO Headers

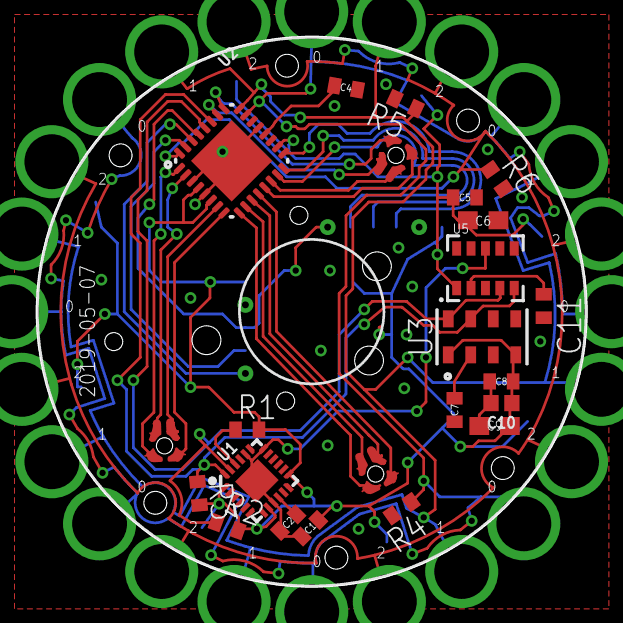
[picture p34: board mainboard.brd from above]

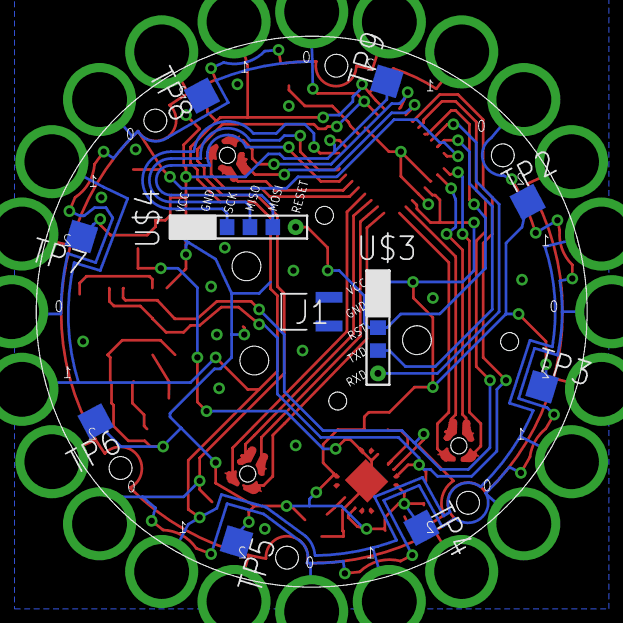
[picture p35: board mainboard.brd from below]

Board: 2 copper layers, 30.6 x 30.6 mm, 33 parts (11 on the bottom side), 31 nets.

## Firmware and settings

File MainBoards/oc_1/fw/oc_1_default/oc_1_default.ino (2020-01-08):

/*
oc_1_default.ino - Default firmware for OpenChronograph OC-1 mainboard.

ToDo:
 - Clean up
 - Improve documentation

Each cycle through:
 1) Update inputs (time, IMU, mag, etc)
 2) Update hand states {pos, vel, cmd)
 3) Step hands

Each mode defines a set of inputs required and hand state update functions.
Button events are handled as interrupts, and modify the mode. 
*/

#define MPL

//#include <math.h>
#include <pins_arduino.h>
#include "src/boardconfig_oc1.h"
#include "src/soprod.h"
#include "src/imu.h"
//#include "clock.h"
#include "src/timeval.h"
#include "src/clock_timeval.h"
#include "src/thirdparty/Time/Time.h"   // For converting RTC output to Unix time
#include "src/buttons.h"

#include <avr/sleep.h>
#include <avr/power.h>
#include "src/thirdparty/Low-Power/LowPower.h"

#ifdef MPL
// For pressure sensor driver
#include "src/thirdparty/SparkFun_MPL3115A2_Breakout_Arduino_Library/src/SparkFunMPL3115A2.h" 
#endif

// For RTC driver
#include "src/thirdparty/SparkFun_RV-1805_Arduino_Library/src/SparkFun_RV1805.h"

//#include <PinChangeInterrupt.h>    // For button interrupts
#include "src/thirdparty/PinChangeInterrupt/src/PinChangeInterrupt.h"

#include <Wire.h>                  // To configure I2C speed



#define DEG2RAD (PI / 180.0f)
#define RAD2DEG (1/DEG2RAD)


enum btn_map {
  BTN_INCR,
  BTN_MODE,
  BTN_DECR,
};

button_t buttons[] = {
  {.btn_pin = PD2,
   .btn_state = 0,
   .last_btn_state = 0,
   .last_debounce_time = 0,
   .debounce_delay_ms = 100,
   .last_pressed_time = 0,
   .last_repeat_time = 0},
  
  {.btn_pin = A1, //PC1,
   .btn_state = 0,
   .last_btn_state = 0,
   .last_debounce_time = 0,
   .debounce_delay_ms = 100,
   .last_pressed_time = 0,
   .last_repeat_time = 0},
  
  {.btn_pin = A0, //PC0,
   .btn_state = 0,
   .last_btn_state = 0,
   .last_debounce_time = 0,
   .debounce_delay_ms = 100,
   .last_pressed_time = 0,
   .last_repeat_time = 0},
};

Clock clock_0;    // Default clock


enum DisplayMode {
  MODE_SET_CLOCK,
  MODE_SET_CLOCK_PHASE,
  MODE_SET_CLOCK_PERIOD,
  MODE_TRADITIONAL_TIME,
  MODE_MAG_HEADING,
  MODE_GYRO_HEADING,
  MODE_PRESSURE_ALT,
  MODE_TEMPERATURE,
  MODE_SET_HR_HAND,
  MODE_SET_MIN_HAND,
  MODE_SET_SEC_HAND,
  };



// Note: indexes need to be complete or compiler gets upset
const uint16_t mode_indicator_angle_map[] = {
  [MODE_SET_CLOCK] = 0,
  [MODE_SET_CLOCK_PHASE] = 15,
  [MODE_SET_CLOCK_PERIOD] = 30,
  [MODE_TRADITIONAL_TIME] = 45,
  [MODE_MAG_HEADING] = 60,
  [MODE_GYRO_HEADING] = 75,
  [MODE_PRESSURE_ALT] = 90,
  [MODE_TEMPERATURE] =  105,
  [MODE_SET_HR_HAND] = 120,
  [MODE_SET_MIN_HAND] = 135,
  [MODE_SET_SEC_HAND] = 150,
};


// Volatile b/c button press interrupts could change at any time
volatile DisplayMode display_mode = MODE_SET_HR_HAND;

#ifdef MPL
MPL3115A2 myPressure;
#endif

RV1805 rtc;
tmElements_t tmSet;
Timeval tv_rtc;

//unsigned long t_millis_slept = 0;
uint32_t ms_to_sleep = 0;     // Used to store number of ms to sleep
uint32_t total_ms_slept = 0;  // Used to correct millis() (clock is off during sleep)

volatile int16_t traditional_time_offset_minutes = 0;
volatile int16_t traditional_time_offset_hours = 0;

bool IMU_is_on = 1;    // Flag indicating whether we have the IMU powered on


void setup() {
  delay(3000);
  
  //Initialize serial and wait for port to open:
  Serial.begin(38400);
  //Serial.println("Serial port opened...");
  
  while (!Serial) {
    ; // wait for serial port to connect. Needed for native USB port only
  }
  

  // Initialize digital IO pins
  // FIXME: Not initializing last three pins
  for(int i = 0; i < N_DIO_PINS-3; i++){
    init_pin_cfg(&pin_cfg[i]);
  }

  
  // Configure I2C bus
  Wire.begin(); //Join the bus as master. 
  //By default .begin() will set I2C SCL to Standard Speed mode of 100kHz
  Wire.setClock(400000); //Optional - set I2C SCL to High Speed Mode of 400kHz


  init_motors();    // Initialize hand motors
  
  cal();



  // Initialize RTC
  //------------------------------------------------------------  
  while(1)
    {
      if (rtc.begin() == false) {
	Serial.println("RTC init failed");
	Serial.flush();
	delay(1000);
      }
      else {
	Serial.println("RTC init OK");
	Serial.flush();
	break;
      }
    }
  

  // rtc.begin() tells rtc to use the RC oscillator
  // The RC oscillator results in invalid hundredths values
  // From pg. 46: "The Hundredths Counter is not available when the RC oscillator is selected"
  // So, let's tell him to use the crystal for now.
  // See pg. 31 in the RV-1805 application manual
  rtc.writeRegister(RV1805_CONF_KEY, RV1805_CONF_OSC); //Unlock again
  rtc.writeRegister(RV1805_OSC_CTRL, 0b00000100); //OSEL=0, ACAL=00, BOS=0, FOS=0, IOPW=1, OFIE=0, ACIE=0
  //rtc.writeRegister(RV1805_OSC_CTRL, 0b00000000); //OSEL=0, ACAL=00, BOS=0, FOS=0, IOPW=1, OFIE=0, ACIE=0
 
  rtc.setToCompilerTime();
  //rtc.setHours(9);
  //rtc.setMinutes(12);
  

  rtc.setPowerSwitchFunction(PSWS_STATIC);  // See pg 22 of the RV-1805 App Manual
  delay(100);

  //poweroff_IMU();
  //rtc.enableSleep();
  /*rtc.setPowerSwitchLock(false);
  delay(100);
  rtc.setStaticPowerSwitchOutput(true);  // Pushes PSW high, starving IMU of ground.
  delay(100);
  rtc.setPowerSwitchLock(true);*/

  delay(100);
  //Serial.println("Telling the RTC to power down the IMU...");
  //rtc.setPowerSwitchLock(false);
  //rtc.setStaticPowerSwitchOutput(false);  // Pushes PSW low, providing IMU with ground.
  //IMU_is_on = false;
  //poweroff_IMU();


  


  // Initialize IMU
  //------------------------------------------------------------
  //poweron_IMU();    // IMU may still be off if Atmega is reset without RTC being power cycled
  init_imu();
  imu_sleep();
  //poweroff_IMU();
  IMU_is_on = 0;


#ifdef MPL
  // Initialize pressure sensor
  //------------------------------------------------------------
  myPressure.begin(); // Get sensor online
  myPressure.setModeAltimeter(); // Measure altitude above sea level in meters
  myPressure.setOversampleRate(7); // Set Oversample to the recommended 128
  myPressure.enableEventFlags(); // Enable all three pressure and temp event flags 

  float altitude = myPressure.readAltitudeFt();
  Serial.print("Alt(ft): ");
  Serial.println(altitude, 2);

  myPressure.setModeStandby();    // Put altimeter into low-power mode (2mA)
 #endif


  // disable ADC
  ADCSRA = 0;

  // turn off everything we can
  power_adc_disable ();
  //power_spi_disable();
  //power_twi_disable();
  //power_timer0_disable();
  //power_timer1_disable();
  //power_usart0_disable();


  // Set initial clock parameters
  //------------------------------------------------------------
  // Standard min hand clock
  /*clock_init(&clock_0);
    clock_0.period.tv_sec = 3600.0;*/

  // 1 tick/s clock
  clock_init(&clock_0);
  clock_0.period.tv_sec = 360.0;


  Serial.flush();
  Serial.print("Free RAM: ");
  Serial.println(freeRam());


  // Set interrupts for buttons.
  // Pull-down resistors normally keep these pins low.
  attachPinChangeInterrupt(digitalPinToPinChangeInterrupt(buttons[BTN_INCR].btn_pin),
			   button_pressed_isr, RISING);
  attachPinChangeInterrupt(digitalPinToPinChangeInterrupt(buttons[BTN_MODE].btn_pin),
			   button_pressed_isr, RISING);
  attachPinChangeInterrupt(digitalPinToPinChangeInterrupt(buttons[BTN_DECR].btn_pin),
			   button_pressed_isr, RISING);

  
  //Serial.println("Initialization complete:");
  Serial.flush();
}


void loop()
{  
  // Disable button interrupts while we're doing stuff
  disablePinChangeInterrupt(digitalPinToPinChangeInterrupt(buttons[BTN_INCR].btn_pin));
  disablePinChangeInterrupt(digitalPinToPinChangeInterrupt(buttons[BTN_MODE].btn_pin));
  disablePinChangeInterrupt(digitalPinToPinChangeInterrupt(buttons[BTN_DECR].btn_pin));
  

  // Give motors opportunity to de-energize coils at beginning of cycle so we're not
  // running them unnecessarily while we update the RTC and clock
  motor_update(&hour_motor, millis() + total_ms_slept);
  motor_update(&min_motor, millis() + total_ms_slept);
  motor_update(&sec_motor, millis() + total_ms_slept);



  // Update RTC
  update_rtc_time();   // Takes 2.5ms(!)

  Serial.print("T_rtc: ");
  Serial.print(tv_rtc.tv_sec);
  Serial.print(".");
  Serial.println(tv_rtc.tv_usec);
  Serial.flush();

  
  /*String currentDate = rtc.stringDateUSA(); //Get the current date in mm/dd/yyyy
  String currentTime = rtc.stringTime(); //Get the time
  Serial.print("\n");
  Serial.print(currentDate);
  Serial.print(" ");
  Serial.println(currentTime); */

  

  // Get updated hand commands
  update_cmds();



  //Run motor updates until hands are where they should be
  while( true ){
    motor_update(&hour_motor, millis() + total_ms_slept);
    motor_update(&min_motor, millis() + total_ms_slept);
    motor_update(&sec_motor, millis() + total_ms_slept);


    // If all motors have reached their targets, break
    if ( hour_motor.angle_meas_deg == hour_motor.angle_cmd_deg &&
	 min_motor.angle_meas_deg == min_motor.angle_cmd_deg &&
	 sec_motor.angle_meas_deg == sec_motor.angle_cmd_deg)
      break;

    // Or if all motors are within 1 tick of target and just waiting for tick
    // to complete (not driving), then we can go ahead and sleep.
    if ( abs(hour_motor.angle_meas_deg - hour_motor.angle_cmd_deg) <= 1 &&
	 (hour_motor.state == WAITING_FWD || hour_motor.state== WAITING_REV) &&
	 
	 abs(min_motor.angle_meas_deg - min_motor.angle_cmd_deg) <= 1 &&
	 (min_motor.state == WAITING_FWD || min_motor.state== WAITING_REV) &&
	 
	 abs(sec_motor.angle_meas_deg - sec_motor.angle_cmd_deg) <= 1 &&
	 (sec_motor.state == WAITING_FWD || sec_motor.state== WAITING_REV))
      break;
    

    /* ---- TO SLEEP OR NOT TO SLEEP ----
      Intuitively we would sleep during motor ticks (10ms); however, the minimum amount
      we can sleep is 15ms, so going to sleep would mean driving the motor coils for an
      extra 5ms AND we get slower tick speeds (10ms/tick vs. 15ms/tick).

      The breakeven point appears to be at a drive duration of between 5ms (80uJ/tick) 
      and 6ms(116uJ/tick). For 5ms, it's more efficient to busywait. For 6ms, it's more 
      efficient to put the MCU to sleep and drive the motor for the minimum sleep time 
      of 15ms. 

      However, for slow clocks like the standard 12-hr clock the sleep current is the
      dominating factor, and the choice to busywait vs. sleep during ticks doesn't 
      make much difference power-wise. So for now we'll busywait to get higher tick speeds.

      If we change our minds, we can uncomment the line below to sleep during motor ticks:
     */
    //total_ms_slept += do_sleep(SOPROD_TTICK_MS);
  }


  
  // Normally handled by ISR, but need to check here or else if we never sleep, buttons
  // will never get checked (because ISRs are disabled during main loop)
  check_buttons();  


  // Print state
  //tm_out();
  //Serial.flush();

  
  // Find out how long we can sleep for
  ms_to_sleep = get_ms_to_next_event();


  Serial.print("ms to next event: ");
  Serial.println(ms_to_sleep);
  Serial.flush();

  
  // Re-enable interrupts so we catch button presses while asleep
  enablePinChangeInterrupt(digitalPinToPinChangeInterrupt(buttons[BTN_INCR].btn_pin));
  enablePinChangeInterrupt(digitalPinToPinChangeInterrupt(buttons[BTN_MODE].btn_pin));
  enablePinChangeInterrupt(digitalPinToPinChangeInterrupt(buttons[BTN_DECR].btn_pin));



  
  // Sleep until next event
  while ( ms_to_sleep > 0 ){
    uint32_t ms_slept;

    ms_slept = do_sleep(ms_to_sleep);
    total_ms_slept += ms_slept;

    // Can't just blindly decrement ms_to_sleep--could underflow
    ms_to_sleep = ms_slept >= ms_to_sleep ? 0 : ms_to_sleep - ms_slept;

    // Break out early if button has been pushed
    if ( buttons[BTN_MODE].btn_state || buttons[BTN_INCR].btn_state || buttons[BTN_DECR].btn_state ){
      ms_to_sleep = 0;
      break;
    }
  }
}


uint32_t do_sleep(uint32_t sleep_ms){
  uint32_t t_millis_slept;
  
  if ( sleep_ms < 15 ){
    // Sleep minimum amount
    //Serial.println("Sleeping 15ms");
    //Serial.flush();
    LowPower.powerDown(SLEEP_15MS, ADC_OFF, BOD_OFF);
    t_millis_slept =  15;
  }
  else if ( sleep_ms < 30 ){
    //Serial.println("Sleeping 15ms");
    //Serial.flush();
    LowPower.powerDown(SLEEP_15MS, ADC_OFF, BOD_OFF);
    t_millis_slept = 15;
  }
  else if ( sleep_ms < 60 ){
    //Serial.println("Sleeping 30ms");
    //Serial.flush();
    LowPower.powerDown(SLEEP_30MS, ADC_OFF, BOD_OFF);
    t_millis_slept = 30;
  }
  else if ( sleep_ms < 120 ){
    //Serial.println("Sleeping 60ms");
    //Serial.flush();
    LowPower.powerDown(SLEEP_60MS, ADC_OFF, BOD_OFF);
    t_millis_slept = 60;
  }
  else if ( sleep_ms < 250 ){
    //Serial.println("Sleeping 120ms");
    //Serial.flush();
    LowPower.powerDown(SLEEP_120MS, ADC_OFF, BOD_OFF);
    t_millis_slept = 120;
  }
  else if ( sleep_ms < 500 ){
    //Serial.println("Sleeping 250ms");
    //Serial.flush();
    LowPower.powerDown(SLEEP_250MS, ADC_OFF, BOD_OFF);
    t_millis_slept = 250;
  }
  else if ( sleep_ms < 1000 ){
    //Serial.println("Sleeping 500ms");
    //Serial.flush();
    LowPower.powerDown(SLEEP_500MS, ADC_OFF, BOD_OFF);
    t_millis_slept = 500;
  }
  else { 
    //Serial.println("Sleeping 1000ms");
    //Serial.flush();
    LowPower.powerDown(SLEEP_1S, ADC_OFF, BOD_OFF);
    t_millis_slept = 1000;
    }
  
  return t_millis_slept;
}


void update_cmds()
{
  float cmd_hr, cmd_min, cmd_sec;

  // Check to see if we need to turn the IMU on or off
  if (display_mode == MODE_MAG_HEADING || display_mode ==  MODE_GYRO_HEADING)
    {
      if (!IMU_is_on)
	{
	  //poweron_IMU();
	  imu_wake();
	  IMU_is_on = 1;
	}

      update_imu();
    }
  else if (IMU_is_on)
    {
      //poweroff_IMU();
      imu_sleep();
      IMU_is_on = 0;
    }

  
  // All command modes must return commands in degrees
  switch(display_mode){

  case MODE_SET_CLOCK:
  case MODE_SET_CLOCK_PHASE:
  case MODE_SET_CLOCK_PERIOD:
    clock_update(&clock_0, tv_rtc);
    
    cmd_hr = clock_0.theta_0 * RAD2DEG;
    cmd_min = clock_0.theta_1 * RAD2DEG;
    break;

  case MODE_TRADITIONAL_TIME:
    get_cmd_traditional_time(&cmd_hr, &cmd_min);
    break;

  case MODE_MAG_HEADING:    
    get_cmd_heading_mag(&cmd_hr, &cmd_min);
    break;
    
  case MODE_GYRO_HEADING:
    get_cmd_heading_gyro(&cmd_hr, &cmd_min);
    break;

#ifdef MPL
  case MODE_PRESSURE_ALT:
    //TODO: Get current pressure altitude
    break;

  case MODE_TEMPERATURE:
    //TODO: Get current temperature
    break;
#endif


  case MODE_SET_HR_HAND:
  case MODE_SET_MIN_HAND:
  case MODE_SET_SEC_HAND:
    cmd_hr = 0;
    cmd_min = 0;
    cmd_sec = 0;
    break;
  }

  // Motors accept commands as integer degrees, so cast to int
  motor_set_cmd(&hour_motor, (int)cmd_hr );
  motor_set_cmd(&min_motor, (int)cmd_min );

  // Second hand indicates mode
  cmd_sec = mode_indicator_angle_map[display_mode];
  motor_set_cmd(&sec_motor, (int)cmd_sec );
}




void update_rtc_time(){
  static uint8_t seconds_last = 0;
  static uint8_t hundredths_last = 0;
  
  if (rtc.updateTime() == false) //Updates the time variables from RTC
  {
    Serial.println("RTC failed");
  }
  
  tmSet.Year = rtc.getYear() + 2000 - 1970;   // rtc reports years since 2000, need 1970 epoch
  tmSet.Month = rtc.getMonth();
  tmSet.Day = rtc.getDate();
  tmSet.Hour = rtc.getHours();
  tmSet.Minute = rtc.getMinutes();
  tmSet.Second = rtc.getSeconds();

  uint8_t rtc_hundredths = rtc.getHundredths();
  
  tv_rtc.tv_sec = makeTime(tmSet);
  tv_rtc.tv_usec = (unsigned long)rtc_hundredths * 10000;

  // Check if seconds has rolled over (hundredths and seconds aren't synched?)
  /*if (tmSet.Second == seconds_last && rtc_hundredths < hundredths_last){
    tv_rtc.tv_sec += 1;
    }*/

  seconds_last = tmSet.Second;
  hundredths_last = rtc_hundredths;
}



unsigned long get_ms_to_next_event(){
  unsigned long t_sleep_ms = 50000;
  unsigned long temp;
  
  float next_theta;
  Timeval tv_to_next_tick;

  

  // Check hour motor tick
  unsigned long t_millis;
  t_millis = millis();
  if ( hour_motor.state != IDLE ){
    temp = t_millis - hour_motor.t_tick_start_ms;
    temp = temp >= SOPROD_TTICK_MS ? 0 : SOPROD_TTICK_MS - temp;
    
    t_sleep_ms = temp < t_sleep_ms ? temp : t_sleep_ms;
  }
  
  // Check min motor tick
  if ( min_motor.state != IDLE ){
    temp = t_millis - min_motor.t_tick_start_ms;
    temp = temp >= SOPROD_TTICK_MS ? 0 : SOPROD_TTICK_MS - temp;
    
    t_sleep_ms = temp < t_sleep_ms ? temp : t_sleep_ms;
  }
  
  // Check sec motor tick
  if ( sec_motor.state != IDLE ){
    temp = t_millis - sec_motor.t_tick_start_ms;
    temp = temp >= SOPROD_TTICK_MS ? 0 : SOPROD_TTICK_MS - temp;
    
    t_sleep_ms = temp < t_sleep_ms ? temp : t_sleep_ms;
  }

  // Check if any buttons are pressed
  if ( buttons[BTN_MODE].btn_state || buttons[BTN_INCR].btn_state || buttons[BTN_DECR].btn_state ){
    t_sleep_ms = BUTTON_PRESSED_SLEEP_MS < t_sleep_ms ? BUTTON_PRESSED_SLEEP_MS : t_sleep_ms;
  }
  
  // Check next clock tick start
  switch(display_mode){

  case MODE_SET_CLOCK:
  case MODE_SET_CLOCK_PHASE:
  case MODE_SET_CLOCK_PERIOD:   
    // Get current angles
    
    // Find time at next tick (one degree more)
    next_theta = (clock_0.theta_0 + clock_0.theta_1)/2.0f + 1.0f*DEG2RAD;

    tv_to_next_tick = get_time_at_next_theta(&clock_0, next_theta);

    // Convert to ms
    temp = tv_to_next_tick.tv_sec*1000 + tv_to_next_tick.tv_usec/1000;
    
    t_sleep_ms = temp < t_sleep_ms ? temp : t_sleep_ms;
    break;
    
  case MODE_TRADITIONAL_TIME:
    temp = 60000;
    t_sleep_ms = temp < t_sleep_ms ? temp : t_sleep_ms;
    break;
  case MODE_MAG_HEADING:
  case MODE_GYRO_HEADING:
    temp = 0;
    t_sleep_ms = temp < t_sleep_ms ? temp : t_sleep_ms;
    break;
    
  case MODE_PRESSURE_ALT:
  case MODE_TEMPERATURE:
  case MODE_SET_HR_HAND:
  case MODE_SET_MIN_HAND:
  case MODE_SET_SEC_HAND:
    temp = 100;
    t_sleep_ms = temp < t_sleep_ms ? temp : t_sleep_ms;
    break;
  }

  return t_sleep_ms;
}



// Tell RTC to remove power from the IMU
void poweroff_IMU(void)
{
  /* From pg. 68 of the RV1805 user manual:

    If the PSWS field is set to the initial value of 7, the PSW pin will be driven with 
    the static value of the PSWB bit which is initially zero. If this pin is used as the 
    power switch, setting PSWB will remove power from the system and may prevent further 
    access to the RV-1805-C3. In order to insure that this does not happen inadvertently, 
    the LKP bit must be cleared in order to change the PSWB bit to a 1.

  Killing power to the IMU gets us from 14.9 to 6.5uA sleep current (sleep current of the IMU is 8.4uA)
  */
  //Serial.println("Telling the RTC to power down the IMU...");
  rtc.setPowerSwitchLock(false);
  delay(100);
  rtc.setStaticPowerSwitchOutput(true);  // Pushes PSW high, starving IMU of ground.
  delay(100);
  rtc.setPowerSwitchLock(true);
  
  IMU_is_on = false;    // Update flag
  return;
}


// Tell RTC to begin powering the IMU
void poweron_IMU(void)
{
  /* From pg. 68 of the RV1805 user manual:

    If the PSWS field is set to the initial value of 7, the PSW pin will be driven with 
    the static value of the PSWB bit which is initially zero. If this pin is used as the 
    power switch, setting PSWB will remove power from the system and may prevent further 
    access to the RV-1805-C3. In order to insure that this does not happen inadvertently, 
    the LKP bit must be cleared in order to change the PSWB bit to a 1.

  Killing power to the IMU gets us from 14.9 to 6.5uA sleep current (sleep current of the IMU is 8.4uA)
  */
  //Serial.println("Telling the RTC to power up the IMU...");
  rtc.setPowerSwitchLock(false);
  delay(100);
  rtc.setStaticPowerSwitchOutput(false);  // Pulls PSW low, providng IMU with ground.
  delay(100);
  rtc.setPowerSwitchLock(true);
  
  IMU_is_on = true;    // Update flag
}



// Command Functions -----------------------------------------------------------
void get_cmd_traditional_time(float* p_cmd_hr, float* p_cmd_min)
{
  uint16_t minutes = (tmSet.Minute + traditional_time_offset_minutes) % 60;
  uint8_t hours = (tmSet.Hour + (tmSet.Minute +traditional_time_offset_minutes) / 60) % 12;
  *p_cmd_min = minutes * 6.0f + tmSet.Second * 0.1f;
  *p_cmd_hr = hours * 30.0f + *p_cmd_min * 0.083f;
  Serial.print(tmSet.Hour);
  Serial.print(" ");
  Serial.print(tmSet.Minute);
  Serial.print(" ");
}

void get_cmd_heading_gyro(float* p_cmd_hr, float* p_cmd_min){
  static float theta = 0.0f;
  static unsigned long millis_last = 0;
  float dt_s;

  if (millis_last == 0) millis_last = millis();

  dt_s = (float)(millis() - millis_last) / 1000.0f;
  millis_last = millis();
  theta += myIMU.gz * dt_s;

  *p_cmd_hr = theta;
  *p_cmd_min = theta;
}

void get_cmd_heading_mag(float* p_cmd_hr, float* p_cmd_min){
  float heading;
  
  heading = (atan2( myIMU.my, myIMU.mx ) * RAD2DEG) + 180.0f;  // Gives +/-180 deg

  //heading = filter( heading );

  *p_cmd_hr = heading;
  *p_cmd_min = heading;
}
//------------------------------------------------------------------------------



void check_buttons()
{
  // If MODE pressed, increment mode
  if ( check_button_pressed(&buttons[BTN_MODE]) ){
    //Serial.println("MODE PRESSED");
    mode_pressed();
  }

  // If INCR pressed, increment variable indicted by mode
  if ( check_button_pressed(&buttons[BTN_INCR]) ){
    //Serial.println("INCR PRESSED");
    incr_pressed();
  }
  
  // If DECR pressed, decrement variable indicated by mode
  if ( check_button_pressed(&buttons[BTN_DECR]) ){
    //Serial.println("DECR PRESSED");
    decr_pressed();
  }
}

void button_pressed_isr()
{
  check_buttons();
}
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

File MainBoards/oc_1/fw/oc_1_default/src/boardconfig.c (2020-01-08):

#include <Arduino.h>    // For INPUT, OUTPUT constants
#include "boardconfig.h"


void init_pin_cfg(const DigitalPin* p_pin){
  // Set pin mode
  switch(p_pin->mode){
  case OUTPUT:
    *(p_pin->p_ddport) |= (1 << p_pin->ddpin); // Set pin mode (INPUT, OUTPUT)
    break;
  case INPUT:
    *(p_pin->p_ddport) &= ~(1 << p_pin->ddpin);
    break;
  }

  // Handle pin usage
  switch(p_pin->usage){
  case MOTOR_HF0:
    hour_motor.port_F0 = p_pin->p_port;
    hour_motor.mask_F0 = (1 << p_pin->pin);
    break;
  case MOTOR_HF1:
    hour_motor.port_F1 = p_pin->p_port;
    hour_motor.mask_F1 = (1 << p_pin->pin);
    break;
  case MOTOR_HR0:
    hour_motor.port_R0 = p_pin->p_port;
    hour_motor.mask_R0 = (1 << p_pin->pin);
    break;
  case MOTOR_HR1:
    hour_motor.port_R1 = p_pin->p_port;
    hour_motor.mask_R1 = (1 << p_pin->pin);
    break;

  case MOTOR_MF0:
    min_motor.port_F0 = p_pin->p_port;
    min_motor.mask_F0 = (1 << p_pin->pin);
    break;
  case MOTOR_MF1:
    min_motor.port_F1 = p_pin->p_port;
    min_motor.mask_F1 = (1 << p_pin->pin);
    break;
  case MOTOR_MR0:
    min_motor.port_R0 = p_pin->p_port;
    min_motor.mask_R0 = (1 << p_pin->pin);
    break;
  case MOTOR_MR1:
    min_motor.port_R1 = p_pin->p_port;
    min_motor.mask_R1 = (1 << p_pin->pin);
    break;

  case MOTOR_SF0:
    sec_motor.port_F0 = p_pin->p_port;
    sec_motor.mask_F0 = (1 << p_pin->pin);
    break;
  case MOTOR_SF1:
    sec_motor.port_F1 = p_pin->p_port;
    sec_motor.mask_F1 = (1 << p_pin->pin);
    break;
  case MOTOR_SR0:
    sec_motor.port_R0 = p_pin->p_port;
    sec_motor.mask_R0 = (1 << p_pin->pin);
    break;
  case MOTOR_SR1:
    sec_motor.port_R1 = p_pin->p_port;
    sec_motor.mask_R1 = (1 << p_pin->pin);
    break;

    //case BUTTON_INCR:
  }
}

void init_motors(){
  hour_motor.pole = 0;
  hour_motor.angle_meas_deg = 0;
  hour_motor.angle_cmd_deg = 0;

  min_motor.pole = 0;
  min_motor.angle_meas_deg = 0;
  min_motor.angle_cmd_deg = 0;

  sec_motor.pole = 0;
  sec_motor.angle_meas_deg = 0;
  sec_motor.angle_cmd_deg = 0;
}

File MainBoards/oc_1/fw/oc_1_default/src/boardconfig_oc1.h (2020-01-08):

#ifndef __BOARDCONFIG_MARK_II_H__
#define __BOARDCONFIG_MARK_II_H__

#ifdef __cplusplus
extern "C" {
#endif

#include <pins_arduino.h>
#include "boardconfig.h"

// Pin Mapping Table
//--------------------------------------------------------------------------------
//Phys Pin    ID    Arduino Pin
// 1          PC6     RESET
// 2          PD0       0     (RX)
// 3          PD1       1     (TX)
// 4          PD2       2
// 5          PD3       3
// 6          PD4       4
// 7          VCC
// 8          GND
// 9          PB6       xtal1
// 10         PB7       xtal2
// 11         PD5       5
// 12         PD6       6
// 13         PD7       7
// 14         PB0       8
// 15         PB1       9
// 16         PB2       10
// 17         PB3       11
// 18         PB4       12
// 19         PB5       13
// 20         AVCC
// 21         AREF
// 22         GND
// 23         PC0       14    (A0)
// 24         PC1       15    (A1)
// 25         PC2       16    (A2)
// 26         PC3       17    (A3)
// 27         PC4       18    (A4)
// 28         PC5       19    (A5)

// ATMEL ATMEGA8 & 168 / ARDUINO
//
//                  +-\/-+
//            PC6  1|    |28  PC5 (AI 5)
//      (D 0) PD0  2|    |27  PC4 (AI 4)
//      (D 1) PD1  3|    |26  PC3 (AI 3)
//      (D 2) PD2  4|    |25  PC2 (AI 2)
// PWM+ (D 3) PD3  5|    |24  PC1 (AI 1)
//      (D 4) PD4  6|    |23  PC0 (AI 0)
//            VCC  7|    |22  GND
//            GND  8|    |21  AREF
//            PB6  9|    |20  AVCC
//            PB7 10|    |19  PB5 (D 13)
// PWM+ (D 5) PD5 11|    |18  PB4 (D 12)
// PWM+ (D 6) PD6 12|    |17  PB3 (D 11) PWM
//      (D 7) PD7 13|    |16  PB2 (D 10) PWM
//      (D 8) PB0 14|    |15  PB1 (D 9) PWM
//                  +----+

// MR0 - Minute Hand, Reverse Drive, Contact 0
// MR1 - Minute Hand, Reverse Drive, Contact 1
// MF0 - Minute Hand, Forward Drive, Contact 0
// ...
// HF1 - Hour Hand, Forward Drive, Contact 1

#define N_DIO_PINS 15
  
const DigitalPin pin_cfg[] = {
  {&PORTC, &DDRC, PC2, DDC2, OUTPUT, MOTOR_HF0, 0},
  {&PORTC, &DDRC, PC3, DDC3, OUTPUT, MOTOR_HF1, 0},
  {&PORTB, &DDRB, PB1, DDB1, OUTPUT, MOTOR_HR0, 0},
  {&PORTB, &DDRB, PB2, DDB2, OUTPUT, MOTOR_HR1, 0},

  {&PORTB, &DDRB, PB0, DDB0, OUTPUT, MOTOR_MF0, 0},
  {&PORTD, &DDRD, PD7, DDD7, OUTPUT, MOTOR_MF1, 0},
  {&PORTD, &DDRD, PD5, DDD5, OUTPUT, MOTOR_MR0, 0},
  {&PORTD, &DDRD, PD6, DDD6, OUTPUT, MOTOR_MR1, 0},

  {&PORTB, &DDRB, PB6, DDB6, OUTPUT, MOTOR_SF0, 0},
  {&PORTB, &DDRB, PB7, DDB7, OUTPUT, MOTOR_SF1, 0},
  {&PORTD, &DDRD, PD3, DDD3, OUTPUT, MOTOR_SR0, 0},
  {&PORTD, &DDRD, PD4, DDD4, OUTPUT, MOTOR_SR1, 0},

  {&PORTC, &DDRC, A0,  DDC0, INPUT, BUTTON_DECR, 0},
  {&PORTC, &DDRC, A1,  DDC1, INPUT, BUTTON_MODE, 0},
  {&PORTD, &DDRD, PD2, DDD2, INPUT, BUTTON_INCR, 0},
};


  

#ifdef __cplusplus
} // extern "C"
#endif

#endif // __BOARDCONFIG_MARK_II_H__

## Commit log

2020-01-08 Initial commit of oc-1 files.
    [45010c6b30a930e722395be228df71050403c276.step, b415eedf545dbc7bcc4de6bb77471575da4e3105.step, bcd90fdfe0211a008e479c846e3d104fc3feab37.step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]
2020-01-13 Added pictures of bare dial pcbs and paint.
2020-01-13 Added spacer ring and caliper photos
2020-01-13 Added a couple more dial examples.

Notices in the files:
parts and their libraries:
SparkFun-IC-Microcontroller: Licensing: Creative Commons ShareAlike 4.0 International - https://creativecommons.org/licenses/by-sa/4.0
